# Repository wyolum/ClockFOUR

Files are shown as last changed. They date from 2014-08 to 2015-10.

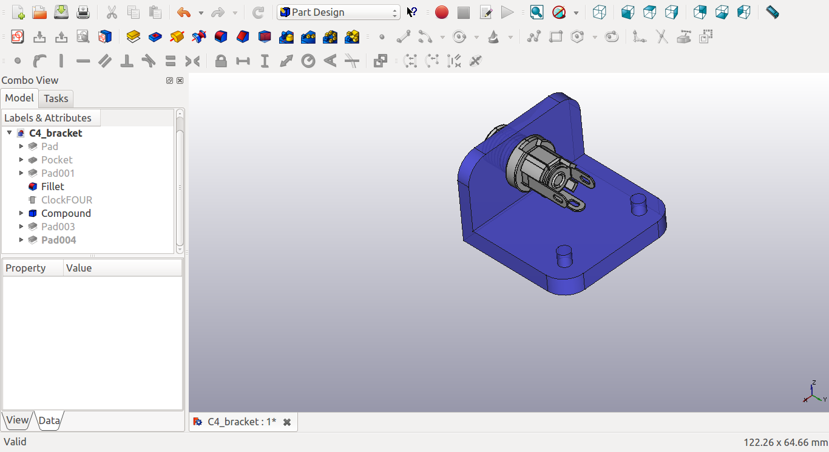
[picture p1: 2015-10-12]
fabricate/Power_Socket_Bracket/C4_bracket_06.png

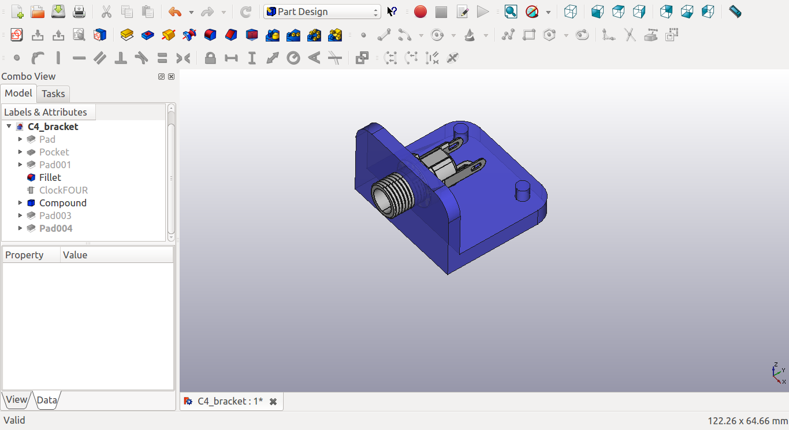
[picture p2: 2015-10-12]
fabricate/Power_Socket_Bracket/C4_bracket_05.png

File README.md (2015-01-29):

ClockFOUR
=========

ClockFOUR is a word clock that tells time with words.  It has a 14x13 matrix of letters that, when illuminated, tells time to the minute.  e.g. “SEVENTEEN MINUTES PAST FOUR”  The clock is 28 x 28 x ~2.6 cm.  The main PCB is approximately 24 x 22 cm and has 182 RGB WS2812B pixels on the front.  The back of the PCB contains an Arduino compatible 328P microprocessor and a DS3231 real time clock chip with 2032 battery backup.  Power is provided by a quality international multi-voltage 5V 3A power supply with barrel connector.

The user interface consists of two touch sensitive buttons wired to top two metal screw posts. Modes and settings are actuated by short taps and long presses.

Development team:
David Pincus (Project leader, software, hardware & design)
Josef Schneider (Software)
Anool Mahidharia (Hardware)

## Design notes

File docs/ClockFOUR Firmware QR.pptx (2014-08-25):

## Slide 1

ClockTiM Firmware 1.0 Quick Reference

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
<Power on>

L

R

Wyolum logo displayed for 3 seconds

Seconds mode

Temperature mode

Splash mode

L

Self test mode

Time mode

Colour ++

L

/

R

L

L

R

L

Set time mode

L

&

R

Enter choice

GPS? Y/N

If N

L

R

If Y – Time and date set by GPS

R – display next hour using words, e.g. ONE, TWO, THREE, FOUR… L – select

Display two large matrix digits with the first digit highlighted. R- advances by 10 minutes per press, e.g. 10, 20, 30. L – select. R – advance minute digit by 1, e.g. 30, 31, 32, 33, etc. L – select.

Toggle Y / N

Set hour mode

Set minute mode (10’s then 1’s)

Set degree mode C/F

L

Deg C/F?

Toggle C/F

R

Last updated 30/7/14

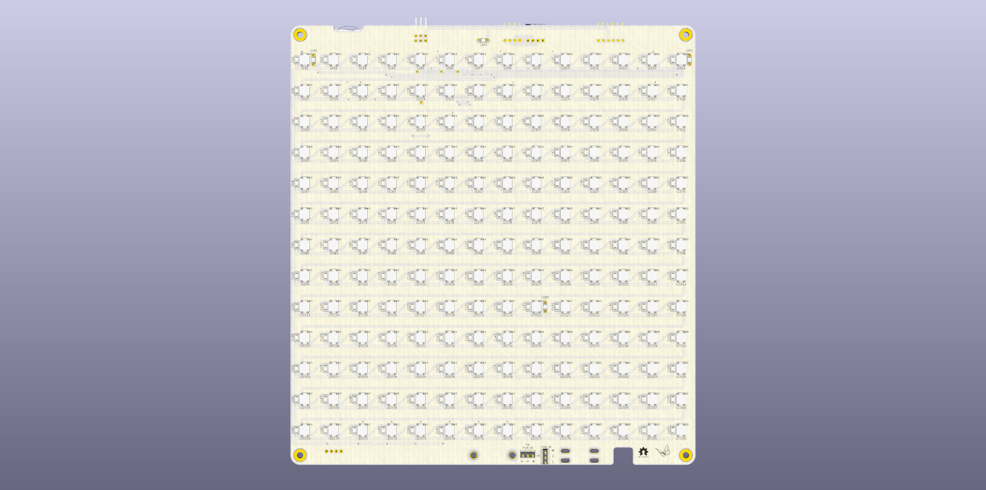
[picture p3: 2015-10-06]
KiCad_bak/3D_Render/ClockFOUR2.png

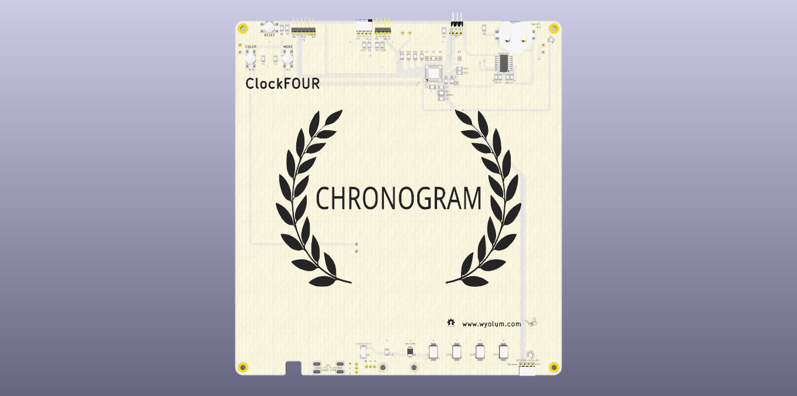
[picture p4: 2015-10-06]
KiCad_bak/3D_Render/ClockFOUR1.png

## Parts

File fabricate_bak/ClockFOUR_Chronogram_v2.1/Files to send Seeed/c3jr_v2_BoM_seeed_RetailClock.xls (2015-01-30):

Electronic Engineering BOM List
Product Name： ClockFOUR – Retail , complete assembled unit
Version：V0.1 | 2.0
Issue Date：29/1/2015
Item No. (序号) | Reference Des (上件位置) | Qty (用量) | Catalog (分类） | Part_Description (规格描述) | Part_Value （元件值） | Part_Package （元件封装） | Manufacturers Name (使用厂牌名称) | Manufacturers Part No. (使用厂牌型号) | Distributors Name （供应商名称） | Distributors Part No. (供貨商型号) | Unit Price （单价） | Price Break To Use （价格分段的购买量） | Notes/Remark （备注）
Example（填写范例）
1 | c4_v2_BoM_seeed | 1 | OTHER | ClockFOUR from Seeed BOM |  | c4_v2_BoM_seeed | Seeed Studio Parts kit and PCB from supplied BOM
2 | baffles_v2_C4.pdf | 15 | OTHER | Vertical Baffle (216x14x2mm black acrylic; 15 per clock) |  | 2mm Thick Acrylic, Black | Laser Cut
3 | baffles_v2_C4.pdf | 14 | OTHER | Horizontal Baffle (218x16x2mm black acrylic; 14 per clock) |  | 2mm Thick Acrylic, Black | Laser Cut
4 | baffles_v2_C4.pdf | 12 | OTHER | Round Localizing Washers (2mm Acrylic Black; Rout=4mm, Rin=1.5mm; 12 per clock) |  | 2mm Thick Acrylic, Black | Laser Cut
5 | sides_C4_v2.pdf | 1 | OTHER | Top, bottom, left & right sides (276 & 270 x20x3mm SMOKED Acrylic) |  | 3mm Thick, Acrylic, SMOKED | Laser Cut
6 | backplate_C4_v2.pdf | 1 | OTHER | Back Plate (280x280x3mm SMOKED Acrylic; Laser cut and etched) |  | 3mm Thick, Acrylic, SMOKED | Laser Cut + Engrave
7 | frontplate_C4_v2.pdf | 1 | OTHER | Front Plate (3mm CLEAR Acrylic; Painted flat black (3 coats), Laser cut and etched) |  | 3mm Thick, Acrylic, Clear | Laser Cut + Engrave
8 |  |  | OTHER | Spray paint front plate (2-3x coats flat black) |  | Flat black spray paint - 2-3x coats, let dry between coats | Seeed Studio
9 |  | 4 | OTHER | M3 Stand Offs 20mm, - Part No : 94868A229 |  | Standoff, M3x20mm, Round, SS | McMaster | 94868A229 |  |  |  |  | http://www.mcmaster.com/#catalog/120/3264/=vcmf9b
10 |  | 4 | OTHER | M3 16mm low head hex screws - Part No : 92855A316 |  | Screw, M3x16mm, Low Head Socket, SS | McMaster | 92855A316 |  |  |  |  | http://www.mcmaster.com/#metric-socket-head-cap-screws/=jroaog
11 |  | 8 | OTHER | M3 10mm low head hex screws - Part No : 92855A310 |  | Screw, M3x10mm, Low Head Socket, SS | McMaster | 92855A310 |  |  |  |  | http://www.mcmaster.com/#catalog/121/3100/=vfpcjh
12 |  | 4 | OTHER | M3 hex nut - Part No : 91828A211 |  | Nut, M3, Hex, SS | McMaster | 91828A211 |  |  |  |  | http://www.mcmaster.com/#metric-hex-nuts/=jroctc
13 |  | 1 | OTHER | Power Supply (5v 3A plug in; plugs for USA, UK, Europe and Australia/China included) |  | ADPT MULTI-BLADE 5VDC 3.0A P5P | CUI inc | EMSA050300-P5P-SZ | Digikey | T1088-P5P-ND |  |  | http://www.digikey.com/product-detail/en/EMSA050300-P5P-SZ/T1088-P5P-ND/2352082
14 | C4 Instructions_v1.pdf | 1 | OTHER | Instructions sheet (1 printed page B&W A4 size) |  |  | Seeed Studio
15 |  | 1 | OTHER | Velum Paper (220x220mm)
16 |  | 4 | OTHER | clear tape (to hold down velum paper)
17 |  | 1 | OTHER | CR2032 3v lithium coin cell |  |  |  |  | Digikey | P189-ND |  |  | http://www.digikey.com/product-detail/en/CR2032/P189-ND/31939
17 |  | 1 | Connector | CONN 2.1MM JACK W/HARD PNL MNT |  |  | CUI Inc | PJ-005A | Digikey | CP-5-ND |  |  | http://www.digikey.com/product-detail/en/PJ-005A/CP-5-ND/165838
18 |  | 1 | Connector | 5-10cm Wires to connect power jack to PCB - solder both sides |  |  | Seeed Studio
19 |  | 1 | OTHER | Packaging material - securely prepare clock for international trasport
20 |  | 4 | OTHER | BUMPER CYLINDRICAL, Tapered0.5" DIA BLK |  |  | 3M | SJ-5012 (BLACK) | Digikey | SJ5012-0-ND |  |  | PARTS KIT ONLY - Customer to install on bottom or back of clock
1. Recommended Distributor: Digi-Key, Mouser, Avnet Express, Farnell.
2. Catalog: Capacitor,Resister,Diode,Connector,Transistor,IC,PROTECTOR CATEGORY,OTHER
3. Required Fields: Item No, Reference Des, Qty, Catalog, Part_Value, Part Package
Optional Fields: Part_Description, Manufacturers Name, Manufacturers Part No, Distributors Name, Distributors Part No, Unit Cost, Price break to use, Notes/Remark

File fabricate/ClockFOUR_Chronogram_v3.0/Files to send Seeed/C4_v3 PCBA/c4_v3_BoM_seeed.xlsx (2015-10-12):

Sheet: Seeed BOM Format
Electronic Engineering BOM List
Product Name： Chronogram
Version：V3.0
Issue Date：07/OCT/2015
Item No. (序号) | Reference Des (上件位置) | Qty (用量) | Catalog (分类） | Part_Description (规格描述) | Part_Value （元件值） | Part_Package （元件封装） | Manufacturers Name (使用厂牌名称) | Manufacturers Part No. (使用厂牌型号) | Distributors Name （供应商名称） | Distributors Part No. (供貨商型号) | Unit Price （单价） | Price Break To Use （价格分段的购买量） | Notes/Remark （备注）
Example（填写范例）
1 | BT1 | 1 | OTHER | HOLDER COIN CELL 20MM SMD | Batt_RTC | 2032 | MPD (Memory Protection Devices) | BK-912 | Digikey | BK-912-ND |  |  | http://www.digikey.com/product-detail/en/BK-912/BK-912-ND/2647825
2 | -- | 1 | OTHER | BATTERY LITHIUM 3V COIN 20MM | CR2032 | 2032 | Panasonic – BSG | CR2032 | Digikey | P189-ND |  |  | http://www.digikey.com/product-detail/en/CR2032/P189-ND/31939
3 | C1,C3,C6,C8,C9,C11, C197,C198,C199 | 9 | Capacitor | CAP CER 0.1UF 25V 10% X7R 0805 | 100nF | 0805 (2012 Metric) | Samsung Electro-Mechanics America, Inc | CL21B104KACNNNC | Digikey | 1276-1099-1-ND |  |  | http://www.digikey.com/product-detail/en/CL21B104KACNNNC/1276-1099-1-ND/3889185
4 | C5,C7 | 2 | Capacitor | CAP CER 22PF 100V 5% NP0 0805 | 22pF | 0805 (2012 Metric) | Samsung Electro-Mechanics America, Inc | CL21C220JCANNNC | Digikey | 1276-2607-1-ND |  |  | http://www.digikey.com/product-detail/en/CL21C220JCANNNC/1276-2607-1-ND/3890693
5 | C10,C194,C195,C196 | 4 | Capacitor | CAP ALUM 47UF 16V 20% SMD | 47uF | 2917 (7343 Metric) | Panasonic Electronic Components | EEF-CX1C470R | Digikey | P16815-1-ND |  |  | http://www.digikey.com/product-detail/en/EEF-CX1C470R/P16815-1-ND/4755585
6 | C12 ~ C193 | 182 | Capacitor | CAP CER 0.1UF 25V 10% X7R 0805 | 100nF | 0805 (2012 Metric) | Samsung Electro-Mechanics America, Inc | CL21B104KACNNNC | Digikey | 1276-1099-1-ND |  |  | http://www.digikey.com/product-detail/en/CL21B104KACNNNC/1276-1099-1-ND/3889185
7 | D1 | 1 | Diode | DIODE ZENER 5.6V 5W DO214AA | SMBJ5339B | DO-214AA, SMB | Micro Commercial Co | SMBJ5339B-TP | Digikey | SMBJ5339B-TPMSCT-ND |  |  | http://www.digikey.com/product-detail/en/SMBJ5339B-TP/SMBJ5339B-TPMSCT-ND/1636205
8 | F1 | 1 | PROTECTOR CATEGORY | Resettable Fuse, POLYSWITCH 16V 2.0A SMD | MiniSMDC200F/16 | 1812 (4532 Metric) | TE Connectivity / Raychem | MINISMDC200F/16-2 | Mouser | 650-MINISMDC200F/162 |  |  | http://www.mouser.ee/ProductDetail/TE-Connectivity-Raychem/MINISMDC200F-16-2/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
9 | LDR4 | 1 | Resister | PHOTOCELL 16-33KOHM | 15k | Thru' Hole | Advanced Photonix Inc | PDV-P8103 | Digikey | PDV-P8103-ND |  |  | http://www.digikey.com/product-detail/en/PDV-P8103/PDV-P8103-ND/480610
10 | LED1 ~ LED182 | 182 | OTHER | WS2812B;4pin;5050 SMD RGB LED with built-in WS2811 IC | WS2812B | 5050 | Ray wu's store Store No.701799 | WS2812B | Ali Express | WS2812B |  |  | http://www.aliexpress.com/store/product/100pcs-WS2812B-4pin-5050-SMD-RGB-LED-with-built-in-WS2811-IC-inside/701799_1202415085.html
11 | P1 | 1 | Connector | CONN HEADER 6POS .100 R/A 15AU DUAL STR | ICSP | Dual row, 0.1” | FCI | 68021-206HLF | Digikey | 609-3343-ND |  |  | http://www.digikey.com/product-detail/en/68021-206HLF/609-3343-ND/1878487
12 | P2, P3 | 1 | Connector | CONN HEADER .100" SNGL STR | FTDI, HEADER_3x1_PWR | 0.100" (2.54mm) Pitch Connector Male | Sullins Connector Solutions | PREC040SAAN-RC | Digikey | S1012EC-40-ND |  |  | http://www.digikey.com/product-detail/en/PREC040SAAN-RC/S1012EC-40-ND/2774814
13 | P5 | 1 | Connector | CONN HEADER .100" SNGL R/A 3POS | HEADER_3x1_PWR | 0.100" (2.54mm) Pitch Connector Male | Sullins Connector Solutions | PRPC003SBAN-M71RC | Digikey | S1111EC-03-ND |  |  | http://www.digikey.com/product-detail/en/PRPC003SBAN-M71RC/S1111EC-03-ND/2775331
14 | R1,R4 | 2 | Resister | RES 470 OHM 1/8W 5% 0805 | 470R | 0805 (2012 Metric) | Stackpole Electronics Inc | RMCF0805JT470R | Digikey | RMCF0805JT470RCT-ND |  |  | http://www.digikey.com/product-detail/en/RMCF0805JT470R/RMCF0805JT470RCT-ND/1942551
15 | R2,R3,R5,R6,R7,R10, R11,R14,R15,R16 | 10 | Resister | RES 10K OHM 1/8W 1% 0805 | 10K | 0805 (2012 Metric) | Stackpole Electronics Inc | RMCF0805FT10K0 | Digikey | RMCF0805FT10K0CT-ND |  |  | http://www.digikey.com/product-detail/en/RMCF0805FT10K0/RMCF0805FT10K0CT-ND/1942435
16 | R8,R9 | 2 | Resister | RES 4.7K OHM 1/8W 5% 0805 | 4K7 | 0805 (2012 Metric) | Stackpole Electronics Inc | RMCF0805JT4K70 | Digikey | RMCF0805JT4K70CT-ND |  |  | http://www.digikey.com/product-detail/en/RMCF0805JT4K70/RMCF0805JT4K70CT-ND/1942570
17 | SW1, SW2, SW3 | 3 | OTHER | SWITCH TACTILE SPST-NO 0.05A 24V | SW_RST, SW_L, SW_R | 6.00mm x 6.00mm SMD | TE Connectivity | FSM6JSMA | Digikey | 450-1133-ND |  |  | http://www.digikey.com/product-detail/en/FSM6JSMA/450-1133-ND/525822
18 | U1 | 1 | IC | IC MCU 8BIT 32KB FLASH 32TQFP | ATMEGA328P | 32-TQFP | Atmel | ATMEGA328P-AU | Digikey | ATMEGA328P-AU-ND |  |  | http://www.digikey.com/product-detail/en/ATMEGA328P-AU/ATMEGA328P-AU-ND/1832260
19 | U2 | 1 | IC | IC RTC CLK/CALENDAR I2C 16-SOIC | DS3231N | 16-SOIC (0.295", 7.50mm Width) | Maxim Integrated Products | DS3231S# | Digikey | DS3231S#-ND |  |  | http://www.digikey.com/product-detail/en/DS3231S%23/DS3231S%23-ND/1197574
20 | X1 | 1 | OTHER | CRYSTAL 16MHZ 9PF SMD | 16MHz | 4-SMD, No Lead (DFN, LCC) | EPSON | TSX-3225 16.0000MF09Z-AC3 | Digikey | SER3628CT-ND |  |  | http://www.digikey.com/product-detail/en/TSX-3225%2016.0000MF09Z-AC3/SER3628CT-ND/1802879
PARTS KIT (DO NOT POPULATE)
1 | P9, P10 | 2 | Connector | CONN HEADER .100" SNGL STR | STACK_R, Marquee | 0.100" (2.54mm) Pitch Connector Male | Sullins Connector Solutions | PREC040SAAN-RC | Digikey | S1012EC-40-ND |  |  | http://www.digikey.com/product-detail/en/PREC040SAAN-RC/S1012EC-40-ND/2774814
2 | P6, P8, R12, R13 | 4 | Resister | RES 0.0 OHM 1/8W JUMP 0805 | 5VEN_L, 5VEN_R, 0R, 0R | 0805 (2012 Metric) | Samsung Electro-Mechanics America, Inc | RC2012J000CS | Digikey | 1276-5466-1-ND |  |  | http://www.digikey.com/product-detail/en/RC2012J000CS/1276-5466-1-ND/3968438
3 | P7 | 1 | Connector | CONN HEADER FEMALE 4POS .1" TIN | STACK_L | 0.100" (2.54mm) Pitch Connector Female | Sullins Connector Solutions | PPTC041LFBN-RC | Digikey | S7002-ND |  |  | http://www.digikey.com/product-detail/en/PPTC041LFBN-RC/S7002-ND/810144
1. Recommended Distributor: Digi-Key, Mouser, Avnet Express, Farnell.
2. Catalog: Capacitor,Resister,Diode,Connector,Transistor,IC,PROTECTOR CATEGORY,OTHER
3. Required Fields: Item No, Reference Des, Qty, Catalog, Part_Value, Part Package
Optional Fields: Part_Description, Manufacturers Name, Manufacturers Part No, Distributors Name, Distributors Part No, Unit Cost, Price break to use, Notes/Remark

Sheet: Sheet4
Id | Designator | Package | Quantity | Designation | Supplier and ref
1 | BT1 | CR2032_SMD2 | 1 | Batt_RTC
2 | C1,C3,C6,C8,C9,C11,C197,C198,C199 | c_0805 | 9 | 100n
3 | C5,C7 | c_0805 | 2 | 22p
4 | C10,C194,C195,C196 | c_2917 | 4 | 47u
5 | C193,C192,C191, C190,C189,C188,C187,C186,C185,C184,C183,C182,C181, C180,C179,C178,C177,C176,C175,C174,C173,C172,C171, C170,C169,C168,C167,C166,C165,C164,C163,C162,C161, C160,C159,C158,C157,C156,C155,C154,C153,C152,C151, C150,C149,C148,C147,C146,C145,C144,C143,C142,C141, C140,C139,C138,C137,C136,C135,C134,C133,C132,C131, C130,C129,C128,C127,C126,C125,C124,C123,C122,C121, C120,C119,C118,C117,C116,C115,C114,C113,C112,C111, C110,C109,C108,C107,C106,C105,C104,C103,C102,C101, C100,C99,C98,C97,C96,C95,C94,C93,C92,C91, C90,C89,C88,C87,C86,C85,C84,C83,C82,C81, C80,C79,C78,C77,C76,C75,C74,C73,C72,C71, C70,C69,C68,C67,C66,C65,C64,C63,C62,C61, C60,C59,C58,C57,C56,C55,C54,C53,C52,C51, C50,C49,C48,C47,C46,C45,C44,C43,C42,C41, C40,C39,C38,C37,C36,C35,C34,C33,C32,C31, C30,C29,C28,C27,C26,C25,C24,C23,C22,C21, C20,C19,C18,C17,C16,C15,C14,C13,C12 | c_0805_led | 182 | 100n
6 | D1 | diode-DO214AA | 1 | SMBJ5339B
7 | F1 | f_1812 | 1 | miniSMDC200F/16
8 | LDR4 | r_0805_ldr | 1 | LDR
9 | LED182,LED181, LED180,LED179,LED178,LED177,LED176,LED175,LED174,LED173,LED172,LED171, LED170,LED169,LED168,LED167,LED166,LED165,LED164,LED163,LED162,LED161, LED160,LED159,LED158,LED157,LED156,LED155,LED154,LED153,LED152,LED151, LED150,LED149,LED148,LED147,LED146,LED145,LED144,LED143,LED142,LED141, LED140,LED139,LED138,LED137,LED136,LED135,LED134,LED133,LED132,LED131, LED130,LED129,LED128,LED127,LED126,LED125,LED124,LED123,LED122,LED121, LED120,LED119,LED118,LED117,LED116,LED115,LED114,LED113,LED112,LED111, LED110,LED109,LED108,LED107,LED106,LED105,LED104,LED103,LED102,LED101, LED100,LED99,LED98,LED97,LED96,LED95,LED94,LED93,LED92,LED91, LED90,LED89,LED88,LED87,LED86,LED85,LED84,LED83,LED82,LED81, LED80,LED79,LED78,LED77,LED76,LED75,LED74,LED73,LED72,LED71, LED70,LED69,LED68,LED67,LED66,LED65,LED64,LED63,LED62,LED61, LED60,LED59,LED58,LED57,LED56,LED55,LED54,LED53,LED52,LED51, LED50,LED49,LED48,LED47,LED46,LED45,LED44,LED43,LED42,LED41, LED40,LED39,LED38,LED37,LED36,LED35,LED34,LED33,LED32,LED31, LED30,LED29,LED28,LED27,LED26,LED25,LED24,LED23,LED22,LED21, LED20,LED19,LED18,LED17,LED16,LED15,LED14,LED13,LED12,LED11, LED10,LED9,LED8,LED7,LED6,LED5,LED4,LED3,LED2,LED1 | RGB_WS2811B | 182 | WS2812B
10 | P1 | ISP | 1 | ICSP
11 | P2 | Header_FTDI | 1 | FTDI
12 | P3,P5 | Header_3x1_PWR | 2 | PWR_IN
13 | R1,R4 | r_0805 | 2 | 470R
14 | R2,R3,R5,R6,R7,R10,R11,R14,R15,R16 | r_0805 | 10 | 10K
15 | R8,R9 | r_0805 | 2 | 4K7
16 | SW1 | SW_SMD | 1 | SW_RST
17 | SW2 | SW_SMD | 1 | SW_L
18 | SW3 | SW_SMD | 1 | SW_R
19 | U1 | TQFP32 | 1 | ATMEGA328P
20 | U2 | DS3231 | 1 | DS3231N
21 | X1 | Xtal_SMD3 | 1 | 16MHz
 | DNP
1 | P6 | r_0805 | 1 | 5VEN_L
2 | P7 | STACK-L | 1 | I2C_L
3 | P8 | r_0805 | 1 | 5VEN_R
4 | P9 | STACK-R | 1 | I2C_R
5 | P10 | Header_4x1 | 1 | Marquee
6 | R12,R13 | r_0805 | 2 | 0R
7 | LDR1,LDR2,LDR3 | r_0805_ldr | 3 | LDR

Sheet: BoM_PCB
Id | Designator | Package | Quantity | Designation | Supplier and ref
1 | BT1 | CR2032_SMD2 | 1 | Batt_RTC
2 | C1,C3,C6,C8,C9,C11,C197,C198,C199 | c_0805 | 9 | 100n
3 | C5,C7 | c_0805 | 2 | 22p
4 | C10,C194,C195,C196 | c_2917 | 4 | 47u
5 | C193,C192,C191,C190,C189,C188,C187,C186,C185,C184,C183,C182,C181,C180,C179,C178,C177,C176,C175,C174,C173,C172,C171,C170,C169,C168,C167,C166,C165,C164,C163,C162,C161,C160,C159,C158,C157,C156,C155,C154,C153,C152,C151,C150,C149,C148,C147,C146,C145,C144,C143,C142,C141,C140,C139,C138,C137,C136,C135,C134,C133,C132,C131,C130,C129,C128,C127,C126,C125,C124,C123,C122,C121,C120,C119,C118,C117,C116,C115,C114,C113,C112,C111,C110,C109,C108,C107,C106,C105,C104,C103,C102,C101,C100,C99,C98,C97,C96,C95,C94,C93,C92,C91,C90,C89,C88,C87,C86,C85,C84,C83,C82,C81,C80,C79,C78,C77,C76,C75,C74,C73,C72,C71,C70,C69,C68,C67,C66,C65,C64,C63,C62,C61,C60,C59,C58,C57,C56,C55,C54,C53,C52,C51,C50,C49,C48,C47,C46,C45,C44,C43,C42,C41,C40,C39,C38,C37,C36,C35,C34,C33,C32,C31,C30,C29,C28,C27,C26,C25,C24,C23,C22,C21,C20,C19,C18,C17,C16,C15,C14,C13,C12 | c_0805_led | 182 | 100n
6 | D1 | diode-DO214AA | 1 | SMBJ5339B
7 | F1 | f_1812 | 1 | miniSMDC200F/16
8 | LDR4 | r_0805_ldr | 1 | LDR
9 | LED20,LED182,LED181,LED180,LED179,LED178,LED177,LED176,LED175,LED174,LED173,LED172,LED171,LED170,LED169,LED168,LED167,LED166,LED165,LED164,LED163,LED162,LED161,LED160,LED159,LED158,LED157,LED156,LED155,LED154,LED153,LED152,LED151,LED150,LED149,LED148,LED147,LED146,LED145,LED144,LED143,LED142,LED141,LED140,LED139,LED138,LED137,LED136,LED135,LED134,LED133,LED132,LED131,LED130,LED129,LED128,LED127,LED126,LED125,LED124,LED123,LED122,LED121,LED120,LED119,LED118,LED117,LED116,LED115,LED114,LED113,LED112,LED111,LED110,LED109,LED108,LED107,LED106,LED105,LED104,LED103,LED102,LED101,LED100,LED99,LED98,LED97,LED96,LED95,LED94,LED93,LED92,LED91,LED90,LED89,LED88,LED87,LED86,LED85,LED84,LED83,LED82,LED81,LED80,LED79,LED78,LED77,LED76,LED75,LED74,LED73,LED72,LED71,LED70,LED69,LED68,LED67,LED66,LED65,LED64,LED63,LED62,LED61,LED60,LED59,LED58,LED57,LED56,LED55,LED54,LED53,LED52,LED51,LED50,LED49,LED48,LED47,LED46,LED45,LED44,LED43,LED42,LED41,LED40,LED39,LED38,LED37,LED36,LED35,LED34,LED33,LED32,LED31,LED30,LED29,LED28,LED27,LED26,LED25,LED24,LED23,LED22,LED21,LED19,LED18,LED17,LED16,LED15,LED14,LED13,LED12,LED11,LED10,LED9,LED8,LED7,LED6,LED5,LED4,LED3,LED2,LED1 | RGB_WS2811B | 182 | WS2812B
10 | P1 | ISP | 1 | ICSP
11 | P2 | Header_FTDI | 1 | FTDI
12 | P3,P5 | Header_3x1_PWR | 2 | PWR_IN
13 | R1,R4 | r_0805 | 2 | 470R
14 | R2,R3,R5,R6,R7,R10,R11,R14,R15,R16 | r_0805 | 10 | 10K
15 | R8,R9 | r_0805 | 2 | 4K7
16 | SW1 | SW_SMD | 1 | SW_RST
17 | SW2 | SW_SMD | 1 | SW_L
18 | SW3 | SW_SMD | 1 | SW_R
19 | U1 | TQFP32 | 1 | ATMEGA328P
20 | U2 | DS3231 | 1 | DS3231N
21 | X1 | Xtal_SMD3 | 1 | 16MHz
 | DNP
22 | P6 | r_0805 | 1 | 5VEN_L
23 | P7 | STACK-L | 1 | I2C_L
24 | P8 | r_0805 | 1 | 5VEN_R
25 | P9 | STACK-R | 1 | I2C_R
26 | P10 | Header_4x1 | 1 | Marquee
27 | R12,R13 | r_0805 | 2 | 0R
28 | LDR1,LDR2,LDR3 | r_0805_ldr | 3 | LDR
 | OTHERS
29 | A6,A7,B2,D7 | BreakOutPad | 4 | CONN_1
30 | L1 | Logo_silk_OSHW_6x6mm | 1 | OSHW
31 | L2,L3 | Logo-WL3 | 2 | Wyolum
32 | L4 | Logo_silk_OSHW_6x6mm | 1 | Chronogram
33 | L5 | wreath2 | 1 | LOGO
34 | S1,S2,S3,S4 | Screw_3mm | 4 | CONN_1
35 | S5,S6 | MtgHole_3mm | 2 | CONN_1
36 | S13,S12,S11,S10 | Slot_tiewrap | 4 | CONN_1

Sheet: BoM_SCH
Reference | Value | Footprint
A6 | CONN_1 | C4_Pretty:BreakOutPad
A7 | CONN_1 | C4_Pretty:BreakOutPad
B2 | CONN_1 | C4_Pretty:BreakOutPad
BT1 | Batt_RTC | C4_Pretty:CR2032_SMD2
C1 | 100n | C4_Pretty:c_0805
C3 | 100n | C4_Pretty:c_0805
C5 | 22p | C4_Pretty:c_0805
C6 | 100n | C4_Pretty:c_0805
C7 | 22p | C4_Pretty:c_0805
C8 | 100n | C4_Pretty:c_0805
C9 | 100n | C4_Pretty:c_0805
C10 | 47u | C4_Pretty:c_2917
C11 | 100n | C4_Pretty:c_0805
C12 | 100n | C4_Pretty:c_0805_led
C13 | 100n | C4_Pretty:c_0805_led
C14 | 100n | C4_Pretty:c_0805_led
C15 | 100n | C4_Pretty:c_0805_led
C16 | 100n | C4_Pretty:c_0805_led
C17 | 100n | C4_Pretty:c_0805_led
C18 | 100n | C4_Pretty:c_0805_led
C19 | 100n | C4_Pretty:c_0805_led
C20 | 100n | C4_Pretty:c_0805_led
C21 | 100n | C4_Pretty:c_0805_led
C22 | 100n | C4_Pretty:c_0805_led
C23 | 100n | C4_Pretty:c_0805_led
C24 | 100n | C4_Pretty:c_0805_led
C25 | 100n | C4_Pretty:c_0805_led
C26 | 100n | C4_Pretty:c_0805_led
C27 | 100n | C4_Pretty:c_0805_led
C28 | 100n | C4_Pretty:c_0805_led
C29 | 100n | C4_Pretty:c_0805_led
C30 | 100n | C4_Pretty:c_0805_led
C31 | 100n | C4_Pretty:c_0805_led
C32 | 100n | C4_Pretty:c_0805_led
C33 | 100n | C4_Pretty:c_0805_led
C34 | 100n | C4_Pretty:c_0805_led
C35 | 100n | C4_Pretty:c_0805_led
C36 | 100n | C4_Pretty:c_0805_led
C37 | 100n | C4_Pretty:c_0805_led
C38 | 100n | C4_Pretty:c_0805_led
C39 | 100n | C4_Pretty:c_0805_led
C40 | 100n | C4_Pretty:c_0805_led
C41 | 100n | C4_Pretty:c_0805_led
C42 | 100n | C4_Pretty:c_0805_led
C43 | 100n | C4_Pretty:c_0805_led
C44 | 100n | C4_Pretty:c_0805_led
C45 | 100n | C4_Pretty:c_0805_led
C46 | 100n | C4_Pretty:c_0805_led
C47 | 100n | C4_Pretty:c_0805_led
C48 | 100n | C4_Pretty:c_0805_led
C49 | 100n | C4_Pretty:c_0805_led
C50 | 100n | C4_Pretty:c_0805_led
C51 | 100n | C4_Pretty:c_0805_led
C52 | 100n | C4_Pretty:c_0805_led
C53 | 100n | C4_Pretty:c_0805_led
C54 | 100n | C4_Pretty:c_0805_led
C55 | 100n | C4_Pretty:c_0805_led
C56 | 100n | C4_Pretty:c_0805_led
C57 | 100n | C4_Pretty:c_0805_led
C58 | 100n | C4_Pretty:c_0805_led
C59 | 100n | C4_Pretty:c_0805_led
C60 | 100n | C4_Pretty:c_0805_led
C61 | 100n | C4_Pretty:c_0805_led
C62 | 100n | C4_Pretty:c_0805_led
C63 | 100n | C4_Pretty:c_0805_led
C64 | 100n | C4_Pretty:c_0805_led
C65 | 100n | C4_Pretty:c_0805_led
C66 | 100n | C4_Pretty:c_0805_led
C67 | 100n | C4_Pretty:c_0805_led
C68 | 100n | C4_Pretty:c_0805_led
C69 | 100n | C4_Pretty:c_0805_led
C70 | 100n | C4_Pretty:c_0805_led
C71 | 100n | C4_Pretty:c_0805_led
C72 | 100n | C4_Pretty:c_0805_led
C73 | 100n | C4_Pretty:c_0805_led
C74 | 100n | C4_Pretty:c_0805_led
C75 | 100n | C4_Pretty:c_0805_led
C76 | 100n | C4_Pretty:c_0805_led
C77 | 100n | C4_Pretty:c_0805_led
C78 | 100n | C4_Pretty:c_0805_led
C79 | 100n | C4_Pretty:c_0805_led
C80 | 100n | C4_Pretty:c_0805_led
C81 | 100n | C4_Pretty:c_0805_led
C82 | 100n | C4_Pretty:c_0805_led
C83 | 100n | C4_Pretty:c_0805_led
C84 | 100n | C4_Pretty:c_0805_led
C85 | 100n | C4_Pretty:c_0805_led
C86 | 100n | C4_Pretty:c_0805_led
C87 | 100n | C4_Pretty:c_0805_led
C88 | 100n | C4_Pretty:c_0805_led
C89 | 100n | C4_Pretty:c_0805_led
C90 | 100n | C4_Pretty:c_0805_led
C91 | 100n | C4_Pretty:c_0805_led
C92 | 100n | C4_Pretty:c_0805_led
C93 | 100n | C4_Pretty:c_0805_led
C94 | 100n | C4_Pretty:c_0805_led
C95 | 100n | C4_Pretty:c_0805_led
C96 | 100n | C4_Pretty:c_0805_led
C97 | 100n | C4_Pretty:c_0805_led
C98 | 100n | C4_Pretty:c_0805_led
C99 | 100n | C4_Pretty:c_0805_led
C100 | 100n | C4_Pretty:c_0805_led
C101 | 100n | C4_Pretty:c_0805_led
C102 | 100n | C4_Pretty:c_0805_led
C103 | 100n | C4_Pretty:c_0805_led
C104 | 100n | C4_Pretty:c_0805_led
C105 | 100n | C4_Pretty:c_0805_led
C106 | 100n | C4_Pretty:c_0805_led
C107 | 100n | C4_Pretty:c_0805_led
C108 | 100n | C4_Pretty:c_0805_led
C109 | 100n | C4_Pretty:c_0805_led
C110 | 100n | C4_Pretty:c_0805_led
C111 | 100n | C4_Pretty:c_0805_led
C112 | 100n | C4_Pretty:c_0805_led
C113 | 100n | C4_Pretty:c_0805_led
C114 | 100n | C4_Pretty:c_0805_led
C115 | 100n | C4_Pretty:c_0805_led
C116 | 100n | C4_Pretty:c_0805_led
C117 | 100n | C4_Pretty:c_0805_led
C118 | 100n | C4_Pretty:c_0805_led
C119 | 100n | C4_Pretty:c_0805_led
C120 | 100n | C4_Pretty:c_0805_led
C121 | 100n | C4_Pretty:c_0805_led
C122 | 100n | C4_Pretty:c_0805_led
C123 | 100n | C4_Pretty:c_0805_led
C124 | 100n | C4_Pretty:c_0805_led
C125 | 100n | C4_Pretty:c_0805_led
C126 | 100n | C4_Pretty:c_0805_led
C127 | 100n | C4_Pretty:c_0805_led
C128 | 100n | C4_Pretty:c_0805_led
C129 | 100n | C4_Pretty:c_0805_led
C130 | 100n | C4_Pretty:c_0805_led
C131 | 100n | C4_Pretty:c_0805_led
C132 | 100n | C4_Pretty:c_0805_led
C133 | 100n | C4_Pretty:c_0805_led
C134 | 100n | C4_Pretty:c_0805_led
C135 | 100n | C4_Pretty:c_0805_led
C136 | 100n | C4_Pretty:c_0805_led
C137 | 100n | C4_Pretty:c_0805_led
C138 | 100n | C4_Pretty:c_0805_led
C139 | 100n | C4_Pretty:c_0805_led
C140 | 100n | C4_Pretty:c_0805_led
C141 | 100n | C4_Pretty:c_0805_led
C142 | 100n | C4_Pretty:c_0805_led
C143 | 100n | C4_Pretty:c_0805_led
C144 | 100n | C4_Pretty:c_0805_led
C145 | 100n | C4_Pretty:c_0805_led
C146 | 100n | C4_Pretty:c_0805_led
C147 | 100n | C4_Pretty:c_0805_led
C148 | 100n | C4_Pretty:c_0805_led
C149 | 100n | C4_Pretty:c_0805_led
C150 | 100n | C4_Pretty:c_0805_led
C151 | 100n | C4_Pretty:c_0805_led
C152 | 100n | C4_Pretty:c_0805_led
C153 | 100n | C4_Pretty:c_0805_led
C154 | 100n | C4_Pretty:c_0805_led
C155 | 100n | C4_Pretty:c_0805_led
C156 | 100n | C4_Pretty:c_0805_led
C157 | 100n | C4_Pretty:c_0805_led
C158 | 100n | C4_Pretty:c_0805_led
C159 | 100n | C4_Pretty:c_0805_led
C160 | 100n | C4_Pretty:c_0805_led
C161 | 100n | C4_Pretty:c_0805_led
C162 | 100n | C4_Pretty:c_0805_led
C163 | 100n | C4_Pretty:c_0805_led
C164 | 100n | C4_Pretty:c_0805_led
C165 | 100n | C4_Pretty:c_0805_led
C166 | 100n | C4_Pretty:c_0805_led
C167 | 100n | C4_Pretty:c_0805_led
C168 | 100n | C4_Pretty:c_0805_led
C169 | 100n | C4_Pretty:c_0805_led
C170 | 100n | C4_Pretty:c_0805_led
C171 | 100n | C4_Pretty:c_0805_led
C172 | 100n | C4_Pretty:c_0805_led
C173 | 100n | C4_Pretty:c_0805_led
C174 | 100n | C4_Pretty:c_0805_led
C175 | 100n | C4_Pretty:c_0805_led
C176 | 100n | C4_Pretty:c_0805_led
C177 | 100n | C4_Pretty:c_0805_led
C178 | 100n | C4_Pretty:c_0805_led
C179 | 100n | C4_Pretty:c_0805_led
C180 | 100n | C4_Pretty:c_0805_led
C181 | 100n | C4_Pretty:c_0805_led
C182 | 100n | C4_Pretty:c_0805_led
C183 | 100n | C4_Pretty:c_0805_led
C184 | 100n | C4_Pretty:c_0805_led
C185 | 100n | C4_Pretty:c_0805_led
C186 | 100n | C4_Pretty:c_0805_led
C187 | 100n | C4_Pretty:c_0805_led
C188 | 100n | C4_Pretty:c_0805_led
C189 | 100n | C4_Pretty:c_0805_led
C190 | 100n | C4_Pretty:c_0805_led
C191 | 100n | C4_Pretty:c_0805_led
C192 | 100n | C4_Pretty:c_0805_led
C193 | 100n | C4_Pretty:c_0805_led
C194 | 47u | C4_Pretty:c_2917
C195 | 47u | C4_Pretty:c_2917
C196 | 47u | C4_Pretty:c_2917
C197 | 100n | C4_Pretty:c_0805
C198 | 100n | C4_Pretty:c_0805
C199 | 100n | C4_Pretty:c_0805
D1 | SMBJ5339B | C4_Pretty:diode-DO214AA
D7 | CONN_1 | C4_Pretty:BreakOutPad
F1 | miniSMDC200F/16 | C4_Pretty:f_1812
L1 | OSHW | C4_Pretty:Logo_silk_OSHW_6x6mm
L2 | Wyolum | C4_Pretty:Logo-WL3
L3 | Wyolum | C4_Pretty:Logo-WL3
L4 | Chronogram | C4_Pretty:Logo_silk_OSHW_6x6mm
L5 | Logo | C4_Pretty:Logo_silk_OSHW_6x6mm
LDR1 | LDR | C4_Pretty:r_0805_ldr
LDR2 | LDR | C4_Pretty:r_0805_ldr
LDR3 | LDR | C4_Pretty:r_0805_ldr
LDR4 | LDR | C4_Pretty:r_0805_ldr
LED1 | WS2812B | C4_Pretty:RGB_WS2811B
LED2 | WS2812B | C4_Pretty:RGB_WS2811B
LED3 | WS2812B | C4_Pretty:RGB_WS2811B
LED4 | WS2812B | C4_Pretty:RGB_WS2811B
LED5 | WS2812B | C4_Pretty:RGB_WS2811B
LED6 | WS2812B | C4_Pretty:RGB_WS2811B
LED7 | WS2812B | C4_Pretty:RGB_WS2811B
LED8 | WS2812B | C4_Pretty:RGB_WS2811B
LED9 | WS2812B | C4_Pretty:RGB_WS2811B
LED10 | WS2812B | C4_Pretty:RGB_WS2811B
LED11 | WS2812B | C4_Pretty:RGB_WS2811B
LED12 | WS2812B | C4_Pretty:RGB_WS2811B
LED13 | WS2812B | C4_Pretty:RGB_WS2811B
LED14 | WS2812B | C4_Pretty:RGB_WS2811B
LED15 | WS2812B | C4_Pretty:RGB_WS2811B
LED16 | WS2812B | C4_Pretty:RGB_WS2811B
LED17 | WS2812B | C4_Pretty:RGB_WS2811B
LED18 | WS2812B | C4_Pretty:RGB_WS2811B
LED19 | WS2812B | C4_Pretty:RGB_WS2811B
LED20 | WS2812B | C4_Pretty:RGB_WS2811B
LED21 | WS2812B | C4_Pretty:RGB_WS2811B
LED22 | WS2812B | C4_Pretty:RGB_WS2811B
LED23 | WS2812B | C4_Pretty:RGB_WS2811B
LED24 | WS2812B | C4_Pretty:RGB_WS2811B
LED25 | WS2812B | C4_Pretty:RGB_WS2811B
LED26 | WS2812B | C4_Pretty:RGB_WS2811B
LED27 | WS2812B | C4_Pretty:RGB_WS2811B
LED28 | WS2812B | C4_Pretty:RGB_WS2811B
LED29 | WS2812B | C4_Pretty:RGB_WS2811B
LED30 | WS2812B | C4_Pretty:RGB_WS2811B
LED31 | WS2812B | C4_Pretty:RGB_WS2811B
LED32 | WS2812B | C4_Pretty:RGB_WS2811B
LED33 | WS2812B | C4_Pretty:RGB_WS2811B
LED34 | WS2812B | C4_Pretty:RGB_WS2811B
LED35 | WS2812B | C4_Pretty:RGB_WS2811B
LED36 | WS2812B | C4_Pretty:RGB_WS2811B
LED37 | WS2812B | C4_Pretty:RGB_WS2811B
LED38 | WS2812B | C4_Pretty:RGB_WS2811B
LED39 | WS2812B | C4_Pretty:RGB_WS2811B
LED40 | WS2812B | C4_Pretty:RGB_WS2811B
LED41 | WS2812B | C4_Pretty:RGB_WS2811B
LED42 | WS2812B | C4_Pretty:RGB_WS2811B
LED43 | WS2812B | C4_Pretty:RGB_WS2811B
LED44 | WS2812B | C4_Pretty:RGB_WS2811B
LED45 | WS2812B | C4_Pretty:RGB_WS2811B
LED46 | WS2812B | C4_Pretty:RGB_WS2811B
LED47 | WS2812B | C4_Pretty:RGB_WS2811B
LED48 | WS2812B | C4_Pretty:RGB_WS2811B
LED49 | WS2812B | C4_Pretty:RGB_WS2811B
LED50 | WS2812B | C4_Pretty:RGB_WS2811B
LED51 | WS2812B | C4_Pretty:RGB_WS2811B
LED52 | WS2812B | C4_Pretty:RGB_WS2811B
LED53 | WS2812B | C4_Pretty:RGB_WS2811B
LED54 | WS2812B | C4_Pretty:RGB_WS2811B
LED55 | WS2812B | C4_Pretty:RGB_WS2811B
LED56 | WS2812B | C4_Pretty:RGB_WS2811B
LED57 | WS2812B | C4_Pretty:RGB_WS2811B
LED58 | WS2812B | C4_Pretty:RGB_WS2811B
LED59 | WS2812B | C4_Pretty:RGB_WS2811B
LED60 | WS2812B | C4_Pretty:RGB_WS2811B
LED61 | WS2812B | C4_Pretty:RGB_WS2811B
LED62 | WS2812B | C4_Pretty:RGB_WS2811B
LED63 | WS2812B | C4_Pretty:RGB_WS2811B
LED64 | WS2812B | C4_Pretty:RGB_WS2811B
LED65 | WS2812B | C4_Pretty:RGB_WS2811B
LED66 | WS2812B | C4_Pretty:RGB_WS2811B
LED67 | WS2812B | C4_Pretty:RGB_WS2811B
LED68 | WS2812B | C4_Pretty:RGB_WS2811B
LED69 | WS2812B | C4_Pretty:RGB_WS2811B
LED70 | WS2812B | C4_Pretty:RGB_WS2811B
LED71 | WS2812B | C4_Pretty:RGB_WS2811B
LED72 | WS2812B | C4_Pretty:RGB_WS2811B
LED73 | WS2812B | C4_Pretty:RGB_WS2811B
LED74 | WS2812B | C4_Pretty:RGB_WS2811B
LED75 | WS2812B | C4_Pretty:RGB_WS2811B
LED76 | WS2812B | C4_Pretty:RGB_WS2811B
LED77 | WS2812B | C4_Pretty:RGB_WS2811B
LED78 | WS2812B | C4_Pretty:RGB_WS2811B
LED79 | WS2812B | C4_Pretty:RGB_WS2811B
LED80 | WS2812B | C4_Pretty:RGB_WS2811B
LED81 | WS2812B | C4_Pretty:RGB_WS2811B
LED82 | WS2812B | C4_Pretty:RGB_WS2811B
LED83 | WS2812B | C4_Pretty:RGB_WS2811B
LED84 | WS2812B | C4_Pretty:RGB_WS2811B
LED85 | WS2812B | C4_Pretty:RGB_WS2811B
LED86 | WS2812B | C4_Pretty:RGB_WS2811B
LED87 | WS2812B | C4_Pretty:RGB_WS2811B
LED88 | WS2812B | C4_Pretty:RGB_WS2811B
LED89 | WS2812B | C4_Pretty:RGB_WS2811B
LED90 | WS2812B | C4_Pretty:RGB_WS2811B
LED91 | WS2812B | C4_Pretty:RGB_WS2811B
LED92 | WS2812B | C4_Pretty:RGB_WS2811B
LED93 | WS2812B | C4_Pretty:RGB_WS2811B
LED94 | WS2812B | C4_Pretty:RGB_WS2811B
LED95 | WS2812B | C4_Pretty:RGB_WS2811B
LED96 | WS2812B | C4_Pretty:RGB_WS2811B
LED97 | WS2812B | C4_Pretty:RGB_WS2811B
LED98 | WS2812B | C4_Pretty:RGB_WS2811B
LED99 | WS2812B | C4_Pretty:RGB_WS2811B
LED100 | WS2812B | C4_Pretty:RGB_WS2811B
LED101 | WS2812B | C4_Pretty:RGB_WS2811B
LED102 | WS2812B | C4_Pretty:RGB_WS2811B
LED103 | WS2812B | C4_Pretty:RGB_WS2811B
LED104 | WS2812B | C4_Pretty:RGB_WS2811B
LED105 | WS2812B | C4_Pretty:RGB_WS2811B
LED106 | WS2812B | C4_Pretty:RGB_WS2811B
LED107 | WS2812B | C4_Pretty:RGB_WS2811B
LED108 | WS2812B | C4_Pretty:RGB_WS2811B
LED109 | WS2812B | C4_Pretty:RGB_WS2811B
LED110 | WS2812B | C4_Pretty:RGB_WS2811B
LED111 | WS2812B | C4_Pretty:RGB_WS2811B
LED112 | WS2812B | C4_Pretty:RGB_WS2811B
LED113 | WS2812B | C4_Pretty:RGB_WS2811B
LED114 | WS2812B | C4_Pretty:RGB_WS2811B
LED115 | WS2812B | C4_Pretty:RGB_WS2811B
LED116 | WS2812B | C4_Pretty:RGB_WS2811B
LED117 | WS2812B | C4_Pretty:RGB_WS2811B
LED118 | WS2812B | C4_Pretty:RGB_WS2811B
LED119 | WS2812B | C4_Pretty:RGB_WS2811B
LED120 | WS2812B | C4_Pretty:RGB_WS2811B
LED121 | WS2812B | C4_Pretty:RGB_WS2811B
LED122 | WS2812B | C4_Pretty:RGB_WS2811B
LED123 | WS2812B | C4_Pretty:RGB_WS2811B
LED124 | WS2812B | C4_Pretty:RGB_WS2811B
LED125 | WS2812B | C4_Pretty:RGB_WS2811B
LED126 | WS2812B | C4_Pretty:RGB_WS2811B
LED127 | WS2812B | C4_Pretty:RGB_WS2811B
LED128 | WS2812B | C4_Pretty:RGB_WS2811B
LED129 | WS2812B | C4_Pretty:RGB_WS2811B
LED130 | WS2812B | C4_Pretty:RGB_WS2811B
LED131 | WS2812B | C4_Pretty:RGB_WS2811B
LED132 | WS2812B | C4_Pretty:RGB_WS2811B
LED133 | WS2812B | C4_Pretty:RGB_WS2811B
LED134 | WS2812B | C4_Pretty:RGB_WS2811B
LED135 | WS2812B | C4_Pretty:RGB_WS2811B
LED136 | WS2812B | C4_Pretty:RGB_WS2811B
LED137 | WS2812B | C4_Pretty:RGB_WS2811B
LED138 | WS2812B | C4_Pretty:RGB_WS2811B
LED139 | WS2812B | C4_Pretty:RGB_WS2811B
LED140 | WS2812B | C4_Pretty:RGB_WS2811B
LED141 | WS2812B | C4_Pretty:RGB_WS2811B
LED142 | WS2812B | C4_Pretty:RGB_WS2811B
LED143 | WS2812B | C4_Pretty:RGB_WS2811B
LED144 | WS2812B | C4_Pretty:RGB_WS2811B
LED145 | WS2812B | C4_Pretty:RGB_WS2811B
LED146 | WS2812B | C4_Pretty:RGB_WS2811B
LED147 | WS2812B | C4_Pretty:RGB_WS2811B
LED148 | WS2812B | C4_Pretty:RGB_WS2811B
LED149 | WS2812B | C4_Pretty:RGB_WS2811B
LED150 | WS2812B | C4_Pretty:RGB_WS2811B
LED151 | WS2812B | C4_Pretty:RGB_WS2811B
LED152 | WS2812B | C4_Pretty:RGB_WS2811B
LED153 | WS2812B | C4_Pretty:RGB_WS2811B
LED154 | WS2812B | C4_Pretty:RGB_WS2811B
LED155 | WS2812B | C4_Pretty:RGB_WS2811B
LED156 | WS2812B | C4_Pretty:RGB_WS2811B
LED157 | WS2812B | C4_Pretty:RGB_WS2811B
LED158 | WS2812B | C4_Pretty:RGB_WS2811B
LED159 | WS2812B | C4_Pretty:RGB_WS2811B
LED160 | WS2812B | C4_Pretty:RGB_WS2811B
LED161 | WS2812B | C4_Pretty:RGB_WS2811B
LED162 | WS2812B | C4_Pretty:RGB_WS2811B
LED163 | WS2812B | C4_Pretty:RGB_WS2811B
LED164 | WS2812B | C4_Pretty:RGB_WS2811B
LED165 | WS2812B | C4_Pretty:RGB_WS2811B
LED166 | WS2812B | C4_Pretty:RGB_WS2811B
LED167 | WS2812B | C4_Pretty:RGB_WS2811B
LED168 | WS2812B | C4_Pretty:RGB_WS2811B
LED169 | WS2812B | C4_Pretty:RGB_WS2811B
LED170 | WS2812B | C4_Pretty:RGB_WS2811B
LED171 | WS2812B | C4_Pretty:RGB_WS2811B
LED172 | WS2812B | C4_Pretty:RGB_WS2811B
LED173 | WS2812B | C4_Pretty:RGB_WS2811B
LED174 | WS2812B | C4_Pretty:RGB_WS2811B
LED175 | WS2812B | C4_Pretty:RGB_WS2811B
LED176 | WS2812B | C4_Pretty:RGB_WS2811B
LED177 | WS2812B | C4_Pretty:RGB_WS2811B
LED178 | WS2812B | C4_Pretty:RGB_WS2811B
LED179 | WS2812B | C4_Pretty:RGB_WS2811B
LED180 | WS2812B | C4_Pretty:RGB_WS2811B
LED181 | WS2812B | C4_Pretty:RGB_WS2811B
LED182 | WS2812B | C4_Pretty:RGB_WS2811B
P1 | ICSP | C4_Pretty:ISP
P2 | FTDI | C4_Pretty:Header_FTDI
P3 | PWR_IN | C4_Pretty:Header_3x1_PWR
P5 | PWR_IN | C4_Pretty:Header_3x1_PWR
P6 | 5VEN_L | C4_Pretty:r_0805
P7 | I2C_L | C4_Pretty:STACK-L
P8 | 5VEN_R | C4_Pretty:r_0805
P9 | I2C_R | C4_Pretty:STACK-R
P10 | Marquee | C4_Pretty:Header_4x1
R1 | 470R | C4_Pretty:r_0805
R2 | 10K | C4_Pretty:r_0805
R3 | 10K | C4_Pretty:r_0805
R4 | 470R | C4_Pretty:r_0805
R5 | 10K | C4_Pretty:r_0805
R6 | 10K | C4_Pretty:r_0805
R7 | 10K | C4_Pretty:r_0805
R8 | 4K7 | C4_Pretty:r_0805
R9 | 4K7 | C4_Pretty:r_0805
R10 | 10K | C4_Pretty:r_0805
R11 | 10K | C4_Pretty:r_0805
R12 | 0R | C4_Pretty:r_0805
R13 | 0R | C4_Pretty:r_0805
R14 | 10K | C4_Pretty:r_0805
R15 | 10K | C4_Pretty:r_0805
R16 | 10K | C4_Pretty:r_0805
S1 | CONN_1 | C4_Pretty:Screw_3mm
S2 | CONN_1 | C4_Pretty:Screw_3mm
S3 | CONN_1 | C4_Pretty:Screw_3mm
S4 | CONN_1 | C4_Pretty:Screw_3mm
S5 | CONN_1 | C4_Pretty:MtgHole_3mm
S6 | CONN_1 | C4_Pretty:MtgHole_3mm
S10 | CONN_1 | C4_Pretty:Slot_tiewrap
S11 | CONN_1 | C4_Pretty:Slot_tiewrap
S12 | CONN_1 | C4_Pretty:Slot_tiewrap
S13 | CONN_1 | C4_Pretty:Slot_tiewrap
SW1 | SW_RST | C4_Pretty:SW_SMD
SW2 | SW_L | C4_Pretty:SW_SMD
SW3 | SW_R | C4_Pretty:SW_SMD
U1 | ATMEGA328P | C4_Pretty:TQFP32
U2 | DS3231N | C4_Pretty:DS3231
X1 | 16MHz | C4_Pretty:Xtal_SMD3

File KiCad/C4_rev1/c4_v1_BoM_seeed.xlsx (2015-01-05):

Electronic Engineering BOM List
Product Name： ClockFOUR
Version：V1.0
Issue Date：10/10/2014
Item No. (序号) | Reference Des (上件位置) | Qty (用量) | Catalog (分类） | Part_Description (规格描述) | Part_Value （元件值） | Part_Package （元件封装） | Manufacturers Name (使用厂牌名称) | Manufacturers Part No. (使用厂牌型号) | Distributors Name （供应商名称） | Distributors Part No. (供貨商型号) | Unit Price （单价） | Price Break To Use （价格分段的购买量） | Notes/Remark （备注）
Example（填写范例）
1 | BT1 | 1 | OTHER | HOLDER COIN CELL 20MM SMD | Batt_RTC | 2032 | MPD (Memory Protection Devices) | BK-912 | Digikey | BK-912-ND |  |  | http://www.digikey.com/product-detail/en/BK-912/BK-912-ND/2647825
2 | C2,C4 | 2 | Capacitor | CAP CER 100PF 50V 10% X7R 0805 | 100pF | 0805 (2012 Metric) | Kemet | C0805C101K5RACTU | Digikey | 399-7981-1-ND |  |  | http://www.digikey.com/product-detail/en/C0805C101K5RACTU/399-7981-1-ND/3471704
3 | C1,C3,C6,C8,C9,C11,C197,C198 | 8 | Capacitor | CAP CER 0.1UF 25V 10% X7R 0805 | 100nF | 0805 (2012 Metric) | Samsung Electro-Mechanics America, Inc | CL21B104KACNNNC | Digikey | 1276-1099-1-ND |  |  | http://www.digikey.com/product-detail/en/CL21B104KACNNNC/1276-1099-1-ND/3889185
4 | C5,C7 | 2 | Capacitor | CAP CER 22PF 100V 5% NP0 0805 | 22pF | 0805 (2012 Metric) | Samsung Electro-Mechanics America, Inc | CL21C220JCANNNC | Digikey | 1276-2607-1-ND |  |  | http://www.digikey.com/product-detail/en/CL21C220JCANNNC/1276-2607-1-ND/3890693
5 | C10,C194,C195,C196 | 4 | Capacitor | CAP ALUM 47UF 16V 20% SMD | 47uF | 2917 (7343 Metric) | Panasonic Electronic Components | EEF-CX1C470R | Digikey | P16815-1-ND |  |  | http://www.digikey.com/product-detail/en/EEF-CX1C470R/P16815-1-ND/4755585
6 | C12 ~ C193 | 182 | Capacitor | CAP CER 0.1UF 25V 10% X7R 0805 | 100nF | 0805 (2012 Metric) | Samsung Electro-Mechanics America, Inc | CL21B104KACNNNC | Digikey | 1276-1099-1-ND |  |  | http://www.digikey.com/product-detail/en/CL21B104KACNNNC/1276-1099-1-ND/3889185
7 | LED1 ~ LED182 | 182 | OTHER | WS2812B;4pin;5050 SMD RGB LED with built-in WS2811 IC | WS2812B | 5050 | Ray wu's store Store No.701799 | WS2812B | Ali Express | WS2812B |  |  | http://www.aliexpress.com/store/product/100pcs-WS2812B-4pin-5050-SMD-RGB-LED-with-built-in-WS2811-IC-inside/701799_1202415085.html
8 | P5 | 1 | Connector | CON PWR JCK 2.0 X 6.0MM W/SHLD | BARREL_JACK | Thru hole, 5.5x2.1 Jack | CUI Inc | PJ-047A | Digikey | CP-047A-ND |  |  | http://www.digikey.com/product-detail/en/PJ-047A/CP-047A-ND/1644575
9 | R1 | 1 | Resister | RES 470 OHM 1/8W 5% 0805 | 470R | 0805 (2012 Metric) | Stackpole Electronics Inc | RMCF0805JT470R | Digikey | RMCF0805JT470RCT-ND |  |  | http://www.digikey.com/product-detail/en/RMCF0805JT470R/RMCF0805JT470RCT-ND/1942551
10 | R3,R4 | 2 | Resister | RES 1M OHM 1/8W 1% 0805 | 1M | 0805 (2012 Metric) | Stackpole Electronics Inc | RMCF0805FT1M00 | Digikey | RMCF0805FT1M00CT-ND |  |  | http://www.digikey.com/product-detail/en/RMCF0805FT1M00/RMCF0805FT1M00CT-ND/1942528
11 | R2,R5,R6,R7 | 4 | Resister | RES 10K OHM 1/8W 1% 0805 | 10K | 0805 (2012 Metric) | Stackpole Electronics Inc | RMCF0805FT10K0 | Digikey | RMCF0805FT10K0CT-ND |  |  | http://www.digikey.com/product-detail/en/RMCF0805FT10K0/RMCF0805FT10K0CT-ND/1942435
12 | R8,R9 | 2 | Resister | RES 4.7K OHM 1/8W 5% 0805 | 4K7 | 0805 (2012 Metric) | Stackpole Electronics Inc | RMCF0805JT4K70 | Digikey | RMCF0805JT4K70CT-ND |  |  | http://www.digikey.com/product-detail/en/RMCF0805JT4K70/RMCF0805JT4K70CT-ND/1942570
13 | SW1 | 1 | OTHER | SWITCH TACTILE SPST-NO 0.05A 12V | SW_RST | 6.00mm x 6.00mm SMD | TE Connectivity | FSM4JSMA | Digikey | 450-1129-ND |  |  | http://www.digikey.com/product-detail/en/FSM4JSMA/450-1129-ND/525821
14 | SW2 | 1 | OTHER | SWITCH TACTILE SPST-NO 0.05A 12V | SW_RST | 6.00mm x 6.00mm SMD | TE Connectivity | FSM4JSMA | Digikey | 450-1129-ND |  |  | http://www.digikey.com/product-detail/en/FSM4JSMA/450-1129-ND/525821
15 | SW3 | 1 | OTHER | SWITCH TACTILE SPST-NO 0.05A 12V | SW_RST | 6.00mm x 6.00mm SMD | TE Connectivity | FSM4JSMA | Digikey | 450-1129-ND |  |  | http://www.digikey.com/product-detail/en/FSM4JSMA/450-1129-ND/525821
16 | U1 | 1 | IC | IC MCU 8BIT 32KB FLASH 32TQFP | ATMEGA328P | 32-TQFP | Atmel | ATMEGA328P-AU | Digikey | ATMEGA328P-AU-ND |  |  | http://www.digikey.com/product-detail/en/ATMEGA328P-AU/ATMEGA328P-AU-ND/1832260
17 | U2 | 1 | IC | IC RTC CLK/CALENDAR I2C 16-SOIC | DS3231N | 16-SOIC (0.295", 7.50mm Width) | Maxim Integrated Products | DS3231S# | Digikey | DS3231S#-ND |  |  | http://www.digikey.com/product-detail/en/DS3231S%23/DS3231S%23-ND/1197574
18 | X1 | 1 | OTHER | CRYSTAL 16MHZ 9PF SMD | 16MHz | 4-SMD, No Lead (DFN, LCC) | EPSON | TSX-3225 16.0000MF09Z-AC3 | Digikey | SER3628CT-ND |  |  | http://www.digikey.com/product-detail/en/TSX-3225%2016.0000MF09Z-AC3/SER3628CT-ND/1802879
PARTS KIT (DO NOT POPULATE)
1 | P1 | 1 | Connector | CONN HEADER .100" DUAL STR 6POS | ICSP | Dual row, 0.1” | Sullins Connector Solutions | PREC003DAAN-RC | Digikey | S2012EC-03-ND |  |  | http://www.digikey.com/product-detail/en/PREC003DAAN-RC/S2012EC-03-ND/2774891
2 | P2, P3, P4, P9 | 4 | Connector | CONN HEADER .100" SNGL STR | FTDI, LDR_Header, Button_Header, I2C_R | 0.100" (2.54mm) Pitch Connector Male | Sullins Connector Solutions | PREC040SAAN-RC | Digikey | S1012EC-40-ND |  |  | http://www.digikey.com/product-detail/en/PREC040SAAN-RC/S1012EC-40-ND/2774814
3 | P6, P8, R12, R13 | 4 | Connector | RES 0.0 OHM 1/8W JUMP 0805 | 5VEN_L, 5VEN_R | 0805 (2012 Metric) | Samsung Electro-Mechanics America, Inc | RC2012J000CS | Digikey | 1276-5466-1-ND |  |  | http://www.digikey.com/product-detail/en/RC2012J000CS/1276-5466-1-ND/3968438
4 | P7 | 1 | Connector | CONN HEADER FEMALE 4POS .1" TIN | I2C_L | 0.100" (2.54mm) Pitch Connector Female | Sullins Connector Solutions | PPTC041LFBN-RC | Digikey | S7002-ND |  |  | http://www.digikey.com/product-detail/en/PPTC041LFBN-RC/S7002-ND/810144
5 | LDR1 | 1 | Resister | PHOTOCELL 16-33KOHM | 16-33KOHM | through hole | Advanced Photonix Inc | PDV-P8103 | Digikey | PDV-P8103-ND |  |  | http://www.digikey.com/product-detail/en/PDV-P8103/PDV-P8103-ND/480610
1. Recommended Distributor: Digi-Key, Mouser, Avnet Express, Farnell.
2. Catalog: Capacitor,Resister,Diode,Connector,Transistor,IC,PROTECTOR CATEGORY,OTHER
3. Required Fields: Item No, Reference Des, Qty, Catalog, Part_Value, Part Package
Optional Fields: Part_Description, Manufacturers Name, Manufacturers Part No, Distributors Name, Distributors Part No, Unit Cost, Price break to use, Notes/Remark

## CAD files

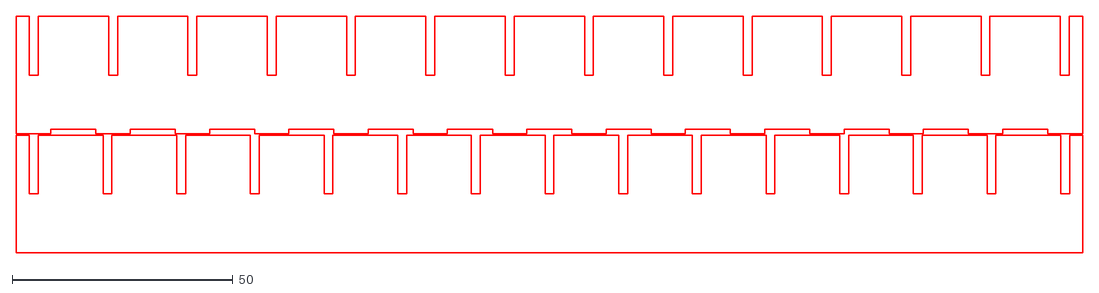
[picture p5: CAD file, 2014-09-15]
fabricate/30x30 size/output/Ready to print/baffles_jr_30_1.0.dxf
241.4 x 53.4

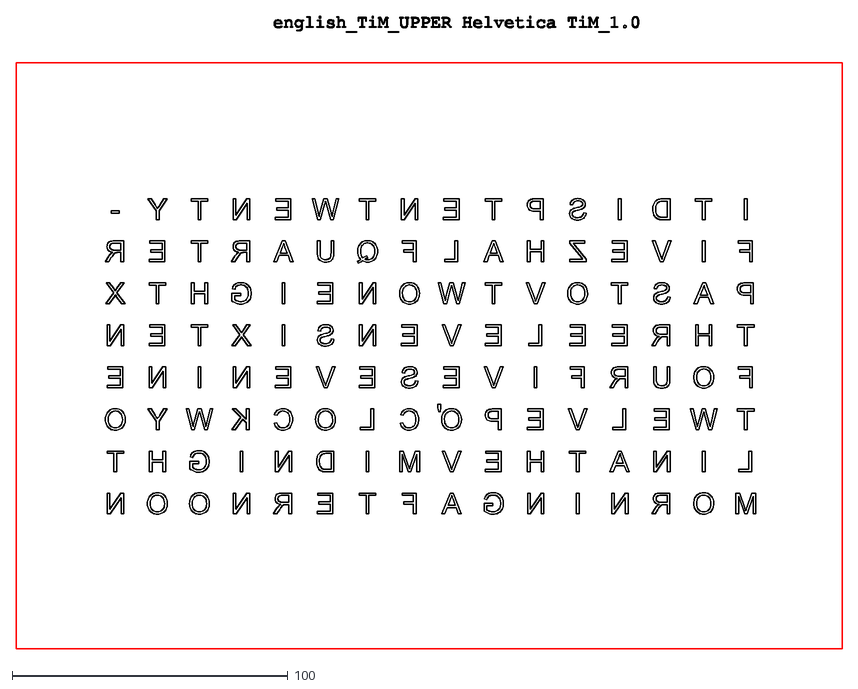
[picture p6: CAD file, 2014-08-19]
fabricate/A4 size/output/english_TiM_UPPER Helvetica_TiM_1.0.dxf
299.5 x 229.3

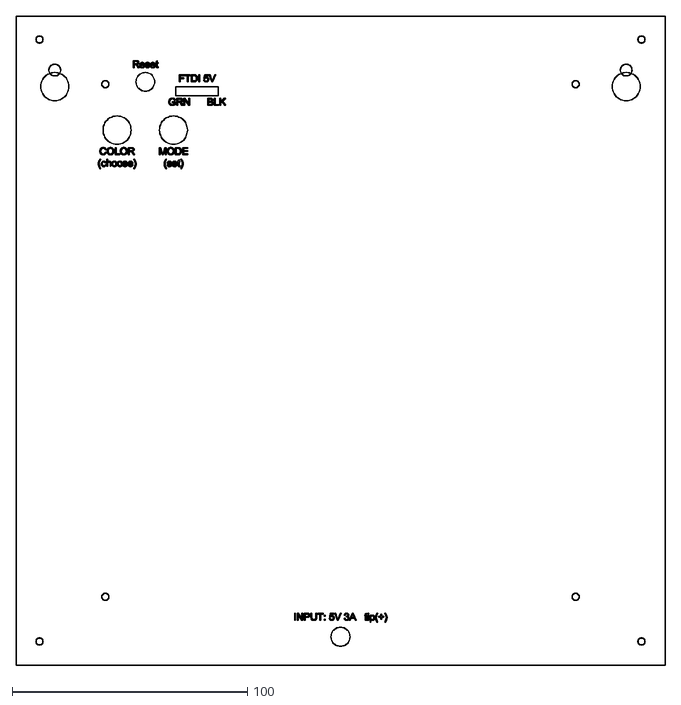
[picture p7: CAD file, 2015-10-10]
fabricate/ClockFOUR_Chronogram_v3.0/output/LASER/backplate_C4_v3.0.dxf
276.0 x 276.0

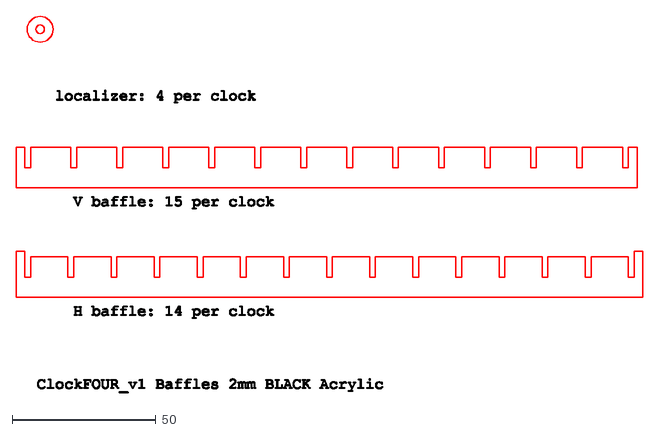
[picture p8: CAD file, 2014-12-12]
fabricate/ClockFOUR_v1/output/1.2mm baffles.dxf
218.0 x 130.9

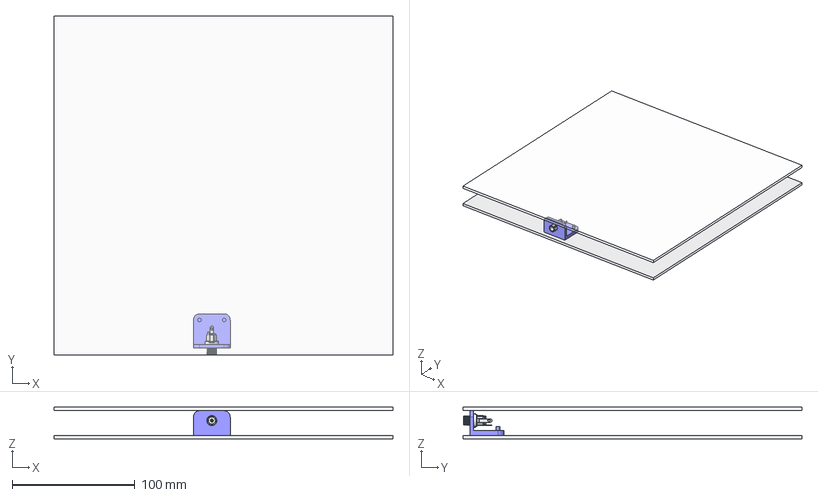
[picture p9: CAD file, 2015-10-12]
fabricate/Power_Socket_Bracket/C4_bracket.fcstd
276.0 x 276.0 x 26.0 mm

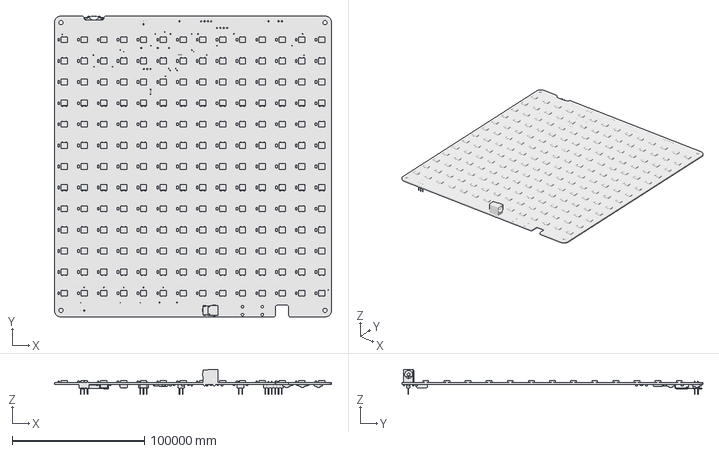
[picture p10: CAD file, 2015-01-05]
KiCad/C4_rev1/ClockFOUR.fcstd
210000.0 x 228020.0 x 19024.1 mm

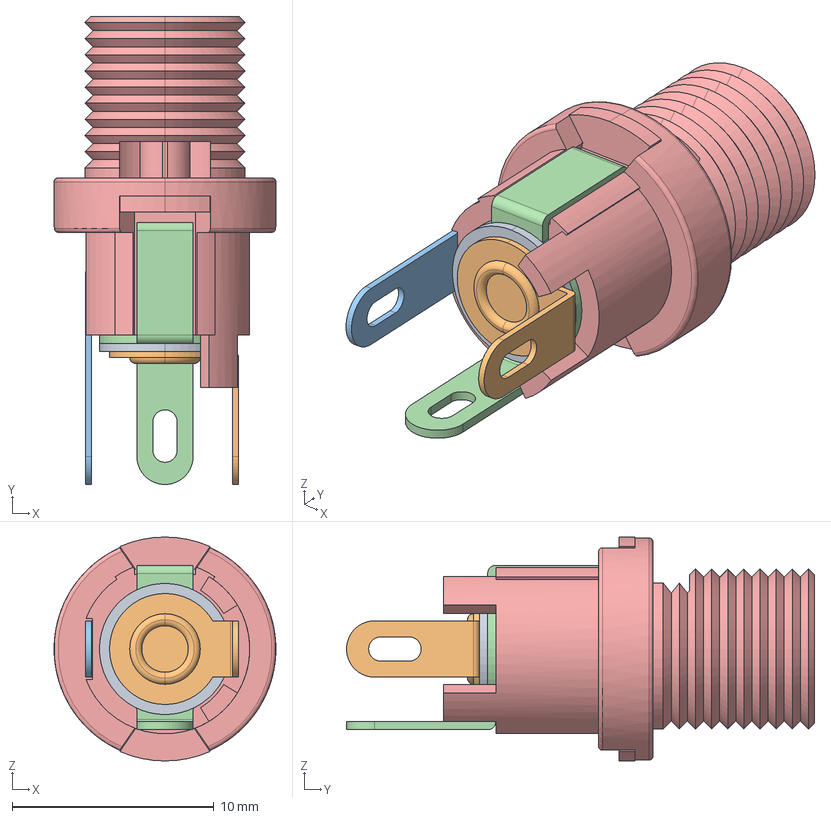
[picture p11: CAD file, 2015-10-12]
KiCad/datasheets/pj-065b.stp
11.0 x 23.2 x 11.1 mm

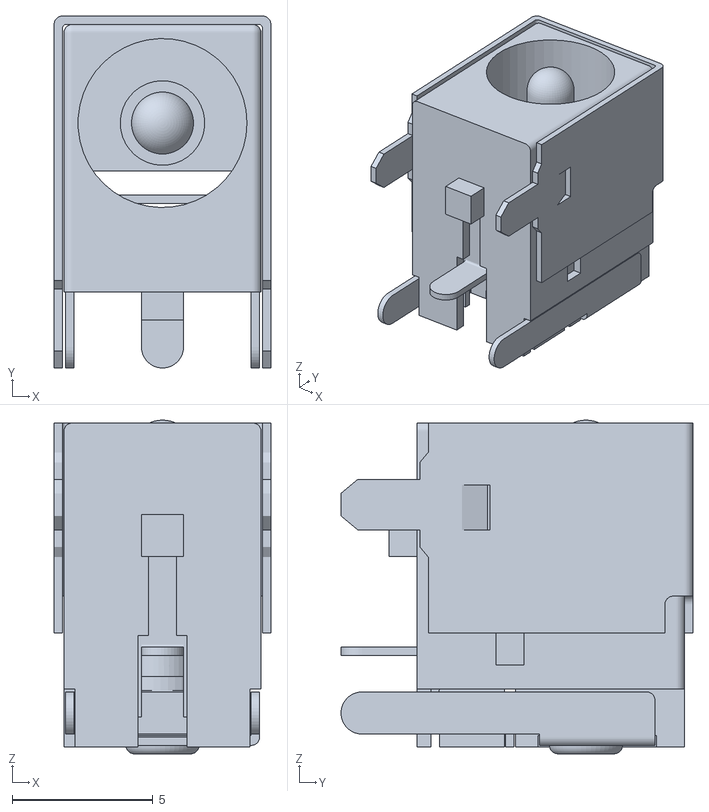
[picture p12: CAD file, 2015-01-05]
KiCad_bak/3d_modules/Barrel_Socket_STL_PJ-047B.stl
7.70 x 12.5 x 11.9

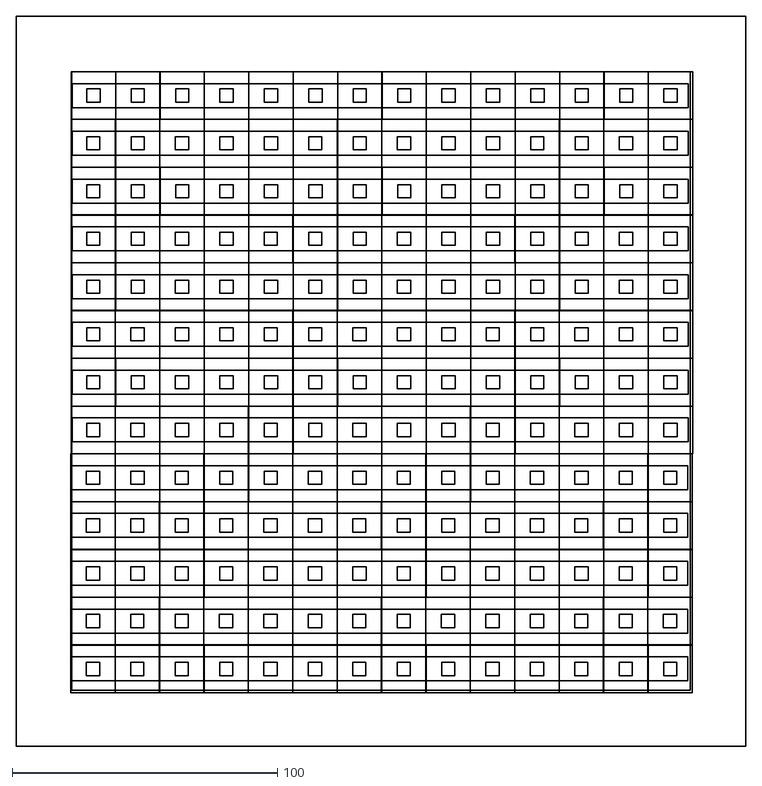
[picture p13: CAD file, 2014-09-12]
fabricate/30x30 size/output/Ready to print/backplate guide.dxf
275.0 x 275.0

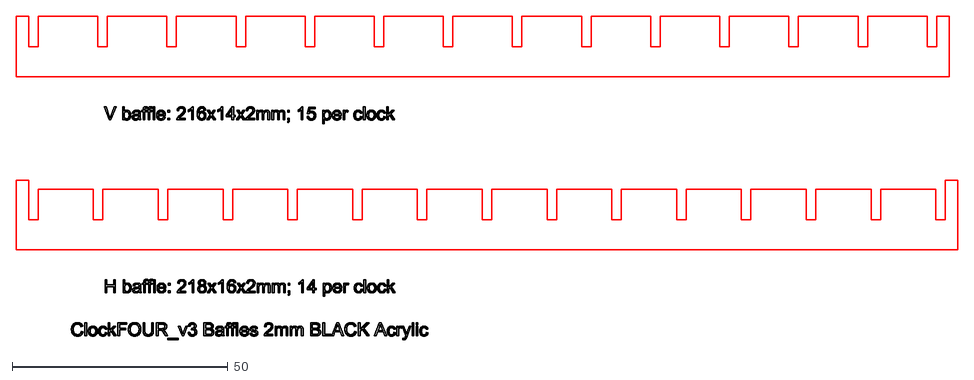
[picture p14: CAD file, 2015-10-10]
fabricate/ClockFOUR_Chronogram_v3.0/output/LASER/baffles_C4_v3.0.dxf
218.0 x 74.9

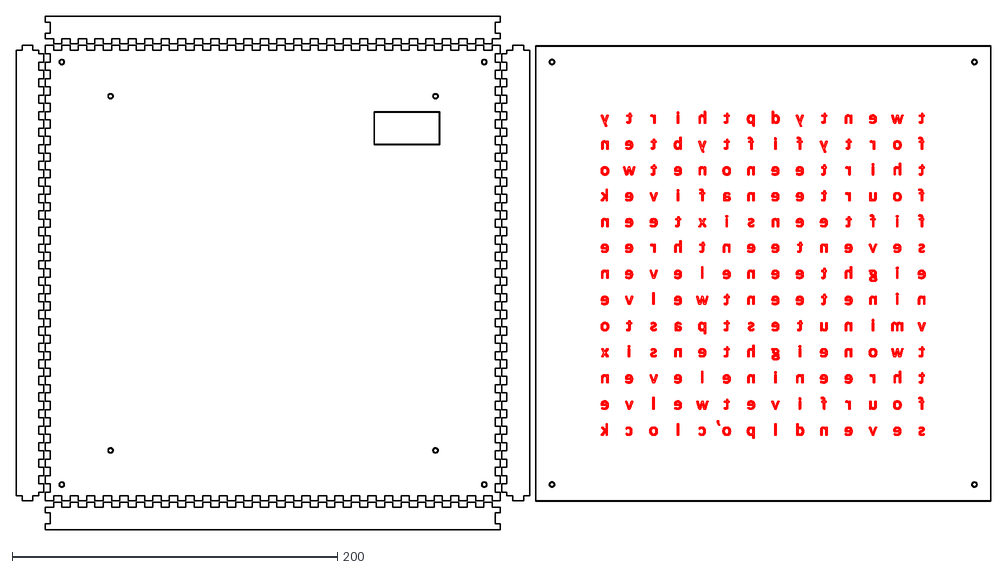
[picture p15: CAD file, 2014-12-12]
fabricate/ClockFOUR_v1/output/ClockFOUR_v1_first try.dxf
599.9 x 316.0

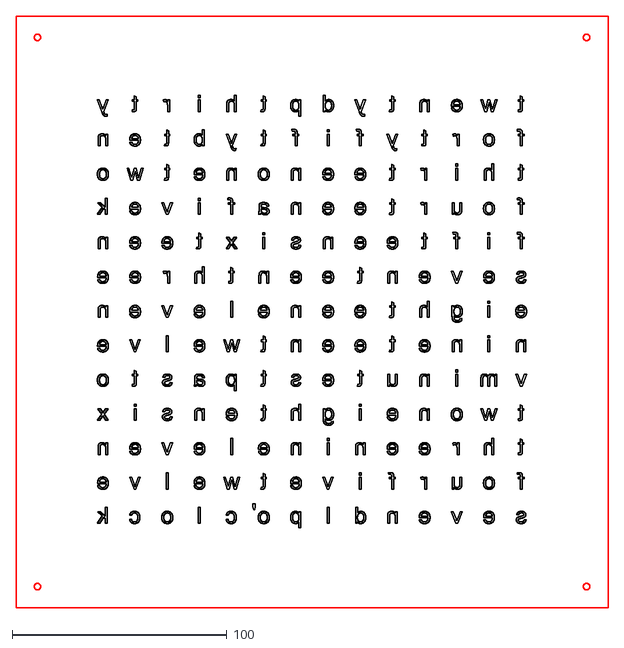
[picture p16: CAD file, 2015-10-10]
fabricate/ClockFOUR_Chronogram_v3.0/output/LASER/english_lower_FINAL Helvetica_C4_v3.0.dxf
276.0 x 276.0

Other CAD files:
KiCad_bak/3D_Render/c4.fcstd
KiCad_bak/3d_modules/Barrel_Socket_STL_PJ-047A.stl
KiCad_bak/archived/C4_rev1/3d_modules/Barrel_Socket_STL_PJ-047A.stl
fabricate/Power_Socket_Bracket/C4_bracket.stl

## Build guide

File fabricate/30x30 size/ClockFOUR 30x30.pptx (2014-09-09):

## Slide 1

60 per meter WS2811B

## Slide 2

11x10

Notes: Canvas 295 ^2
Glass 275 ^2
Viewable glass (in frame) 265 ^2

LED’s 60 / meter WS2811B pixel strips (non waterproof)
Matrix 11 x 10

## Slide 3

12x10

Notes: Canvas 295 ^2
Glass 275 ^2
Viewable glass (in frame) 265 ^2

LED’s 60 / meter WS2811B pixel strips (non waterproof)
Matrix 12 x 10

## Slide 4

12x11

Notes: Canvas 295 ^2
Glass 275 ^2
Viewable glass (in frame) 265 ^2

LED’s 60 / meter WS2811B pixel strips (non waterproof)
Matrix 12 x 11

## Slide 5

14x13

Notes: Canvas 295 ^2
Glass 275 ^2
Viewable glass (in frame) 265 ^2

LED’s 60 / meter WS2811B pixel strips (non waterproof)
Matrix XX x YY

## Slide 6

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
14x13

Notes: Canvas 295 ^2
Glass 275 ^2
Viewable glass (in frame) 265 ^2

LED’s 60 / meter WS2811B pixel strips (non waterproof)
Matrix XX x YY

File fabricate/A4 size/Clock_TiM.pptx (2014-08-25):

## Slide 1

18.29 cm

21.34 cm

30.48 cm

33.39 cm

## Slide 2

18.29 cm

30.48 cm

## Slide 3

18.29 cm

21.34 cm

30.48 cm

33.39 cm

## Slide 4

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
18.29 cm

21.34 cm

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
30.48 cm

33.39 cm

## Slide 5

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
18.29 cm

7.2 in

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
30.48 cm

12 in

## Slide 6

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
18.29 cm

7.2 in

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
30.48 cm

12 in

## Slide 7

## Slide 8

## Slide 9

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
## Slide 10

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
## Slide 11

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
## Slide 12

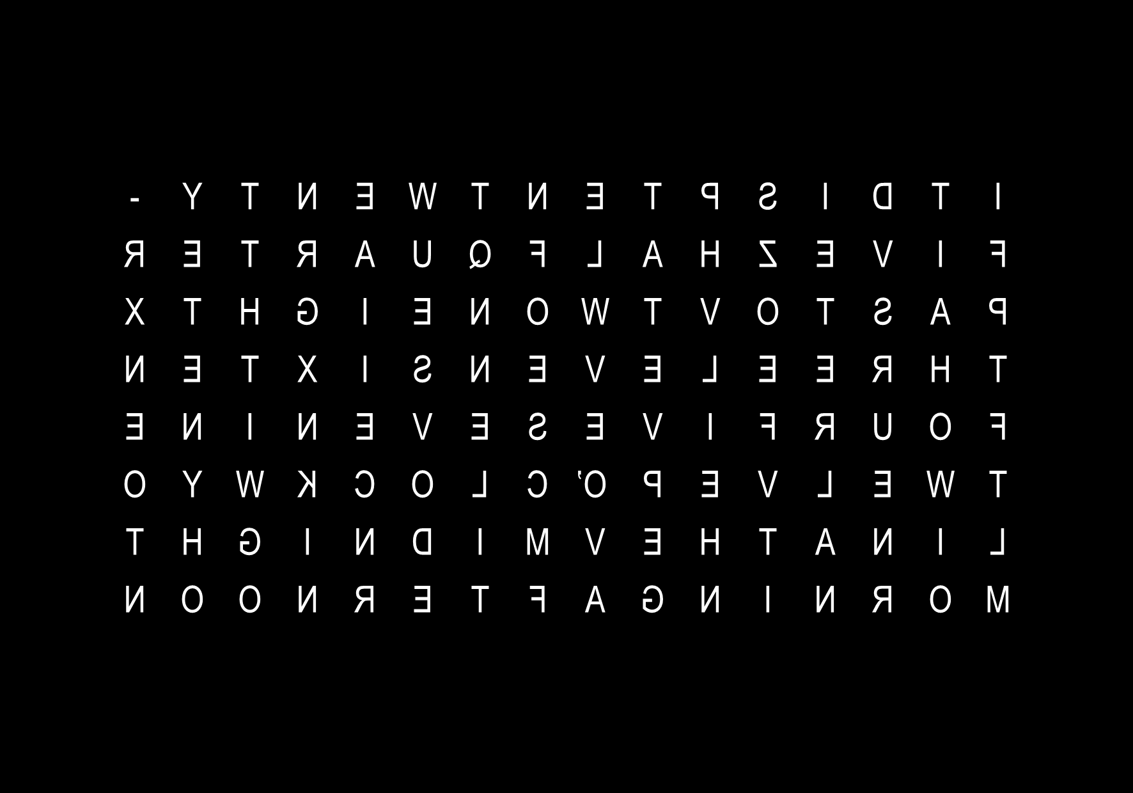
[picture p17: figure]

The black vinyl sheet area is 210 x 300 mm
Cutting area is 120 x 240 mm – white letters (blanks) removed

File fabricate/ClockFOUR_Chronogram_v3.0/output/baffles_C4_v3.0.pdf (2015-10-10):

ClockFOUR baffles C4_v3.0

Localizer: Rout=4mm, Rin=1.5mm; 12 per clock

H baffle: 218x16x2mm; 14 per clock

V baffle: 216x14x2mm; 15 per clock

ClockFOUR_v3 Baffles 2mm BLACK Acrylic

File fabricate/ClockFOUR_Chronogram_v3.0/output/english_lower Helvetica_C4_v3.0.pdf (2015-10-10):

english_lower Helvetica C4_v3.0 276x276x3mm

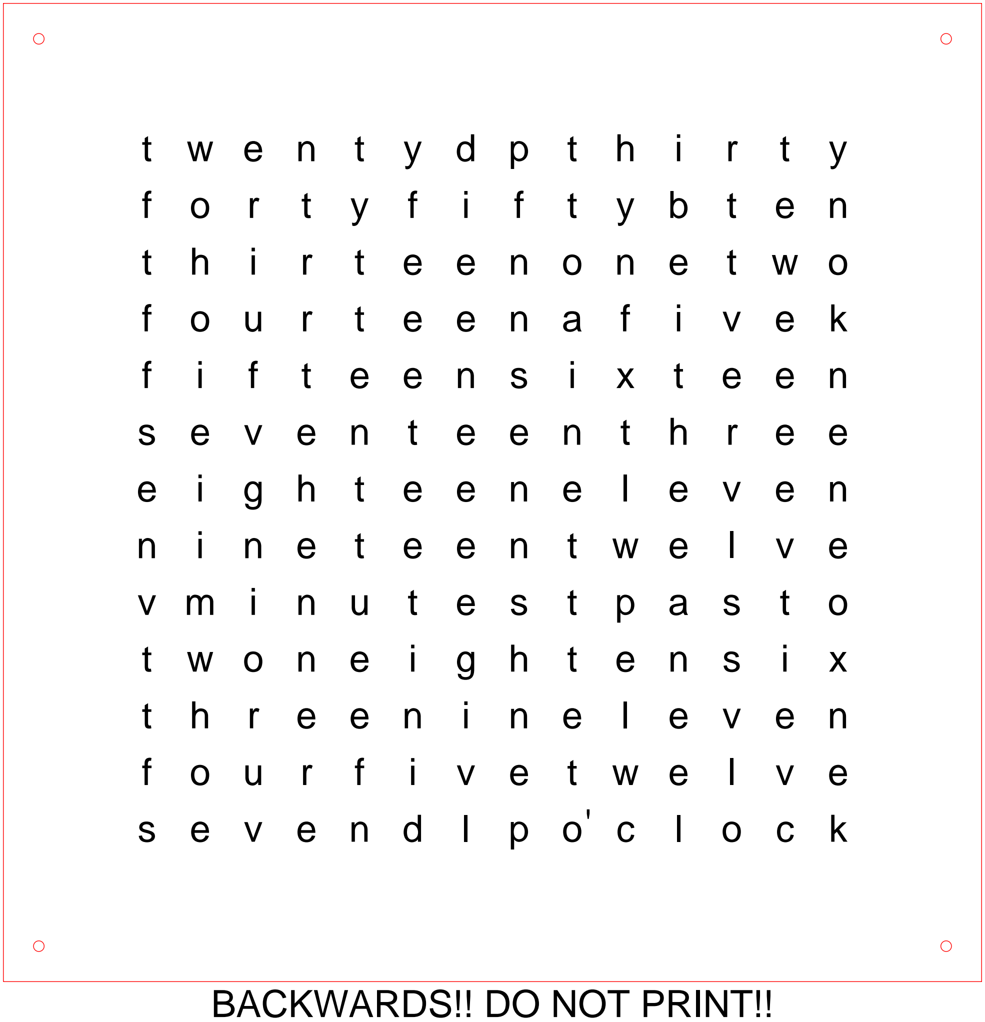
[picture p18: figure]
BACKWARDS!! DO NOT PRINT!!

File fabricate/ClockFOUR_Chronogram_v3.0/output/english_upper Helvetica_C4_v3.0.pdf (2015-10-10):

english_upper Helvetica C4_v3.0 276x276x3mm

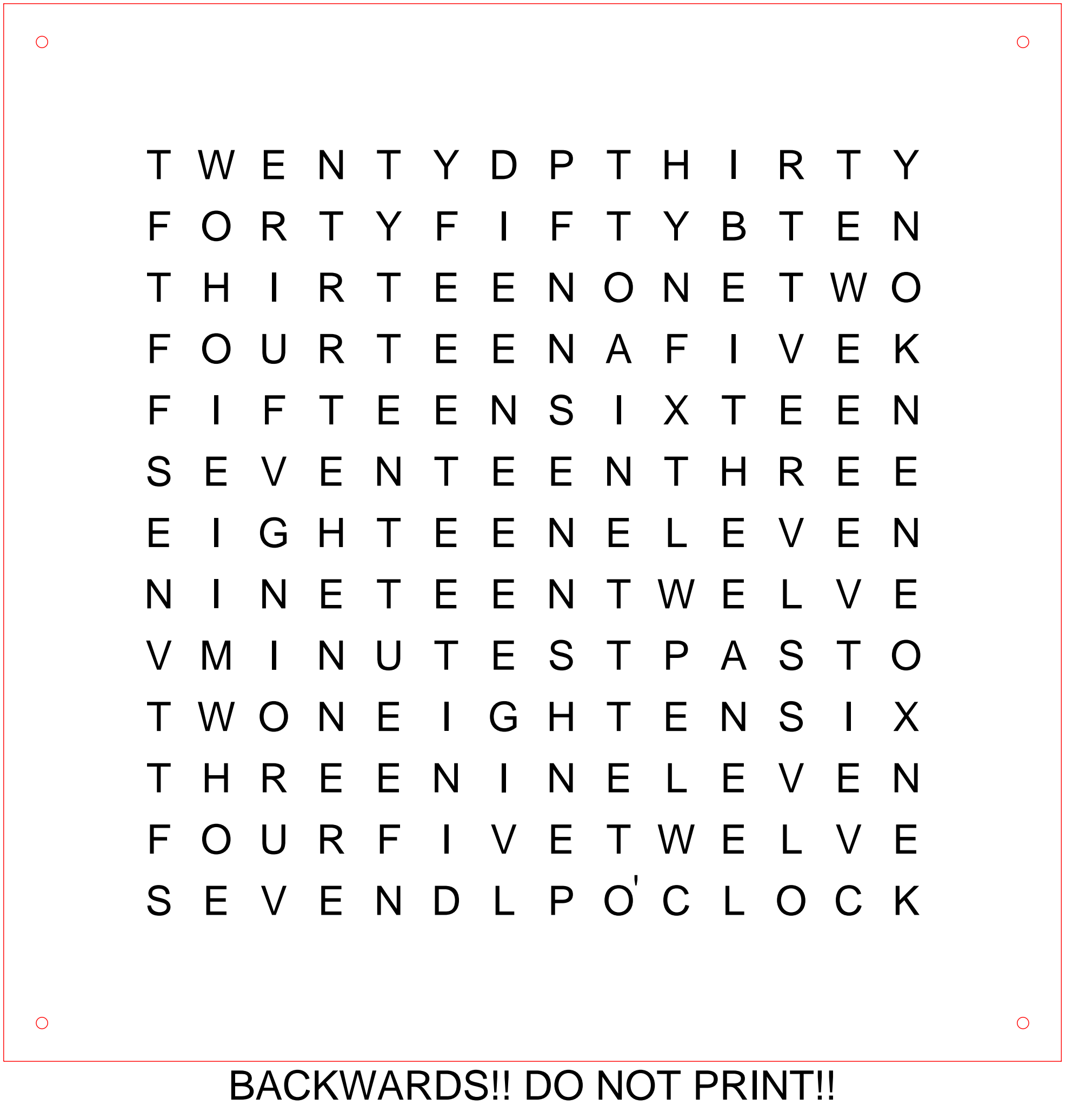
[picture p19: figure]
BACKWARDS!! DO NOT PRINT!!

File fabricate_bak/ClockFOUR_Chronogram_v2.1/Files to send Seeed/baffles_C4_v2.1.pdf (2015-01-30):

ClockFOUR baffles and sides C4_v2.1

Localizer: Rout=4mm, Rin=1.5mm; 12 per clock

H baffle: 218x16x2mm; 14 per clock

V baffle: 216x14x2mm; 15 per clock

ClockFOUR_v2 Baffles 2mm BLACK Acrylic

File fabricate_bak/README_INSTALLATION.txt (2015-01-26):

To create and modify mechanical components for ClockFOUR/Chronogram please install the following pieces of software:

Install Python 2.7x
https://www.python.org/downloads/release/python-279/

PIL for Python 2.7
http://www.pythonware.com/products/pil/

Reportlab for Python 2.7
https://bitbucket.org/rptlab/reportlab

Numpy for Python 2.7
http://sourceforge.net/projects/numpy/files/NumPy/1.9.1/

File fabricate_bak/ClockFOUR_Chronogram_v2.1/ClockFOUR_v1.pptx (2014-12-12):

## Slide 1

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
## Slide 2

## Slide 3

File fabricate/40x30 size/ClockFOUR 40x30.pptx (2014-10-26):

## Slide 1

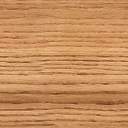
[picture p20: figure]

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
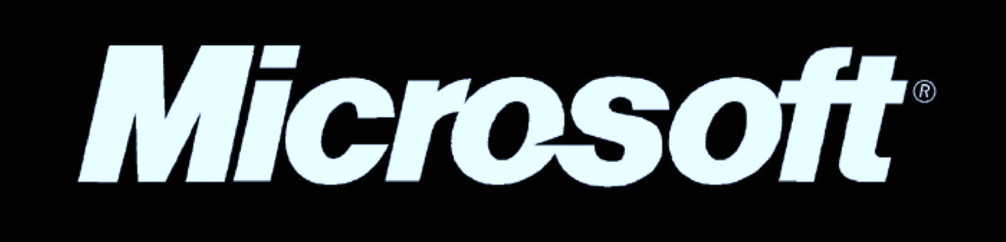
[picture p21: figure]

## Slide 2

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
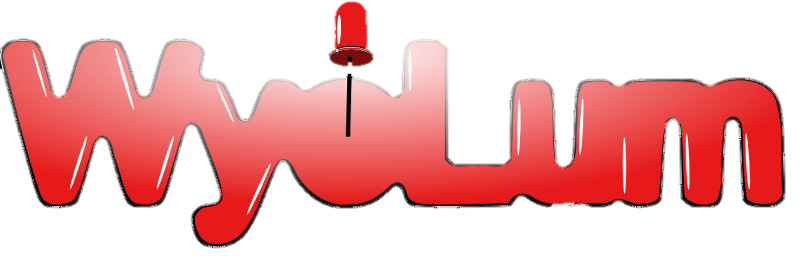
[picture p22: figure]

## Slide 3

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
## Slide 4

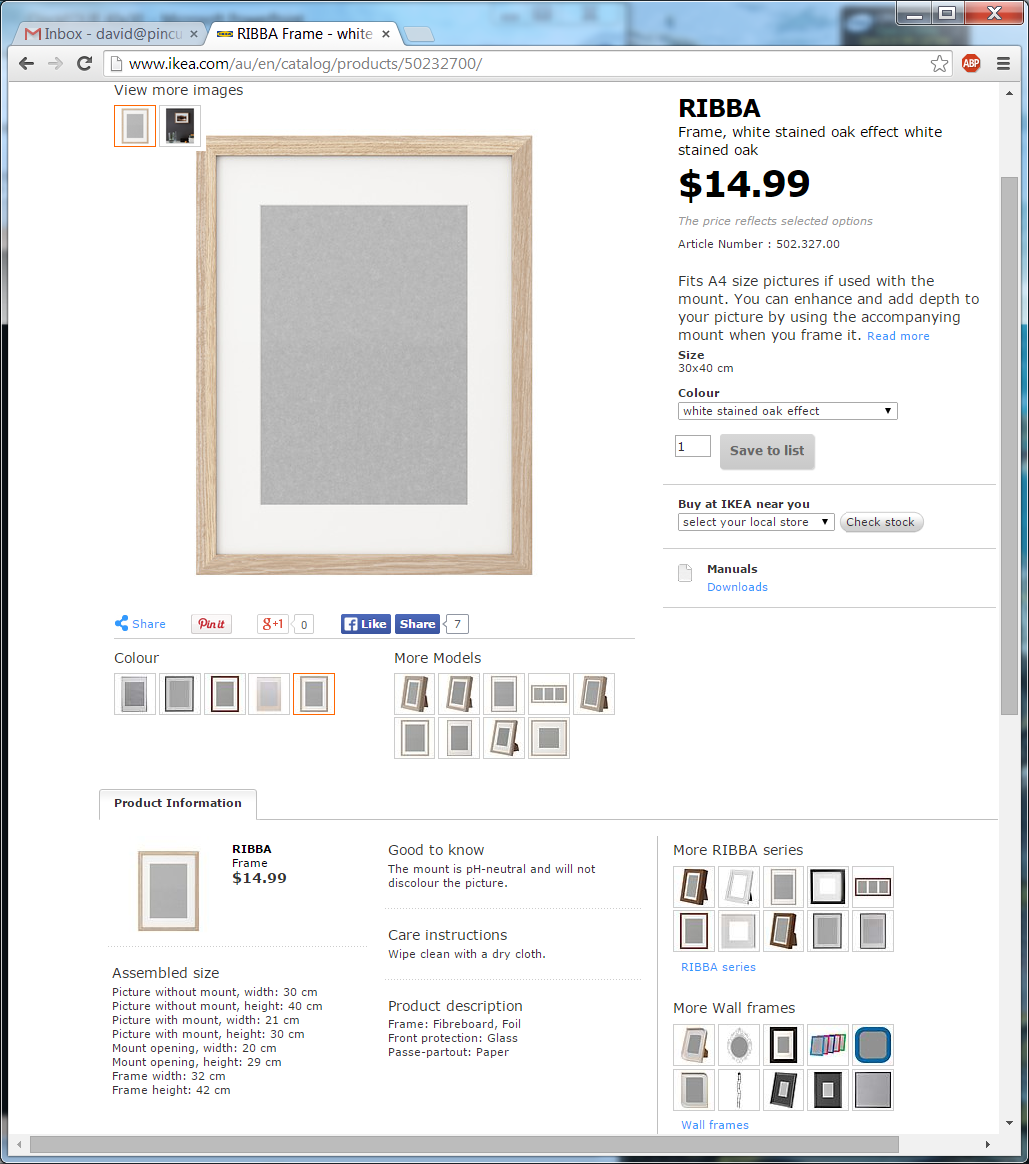
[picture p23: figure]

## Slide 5

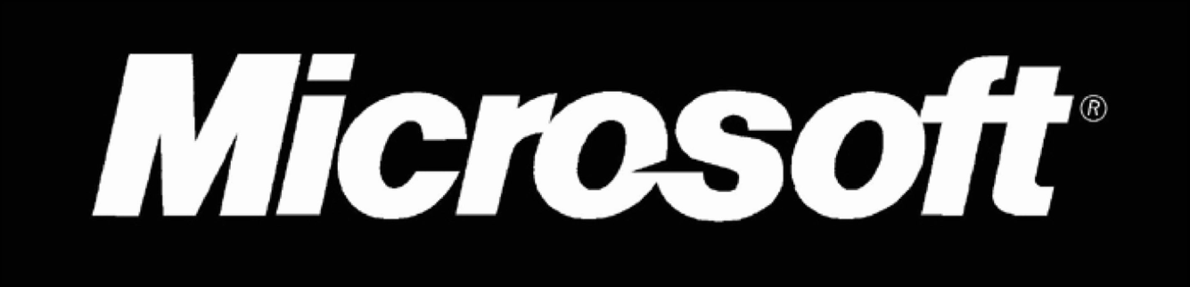
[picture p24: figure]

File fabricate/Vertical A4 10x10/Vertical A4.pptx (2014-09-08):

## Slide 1

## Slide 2

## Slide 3

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
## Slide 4

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
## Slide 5

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
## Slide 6

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
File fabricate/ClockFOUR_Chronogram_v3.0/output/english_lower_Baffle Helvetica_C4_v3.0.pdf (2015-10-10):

english_lower_Baffle Helvetica C4_v3.0 276x276x3mm

BACKWARDS!! DO NOT PRINT!!

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

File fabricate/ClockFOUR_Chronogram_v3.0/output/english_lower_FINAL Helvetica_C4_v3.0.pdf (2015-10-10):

english_lower_FINAL Helvetica C4_v3.0 276x276x3mm

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

'
o p l d n e v e s

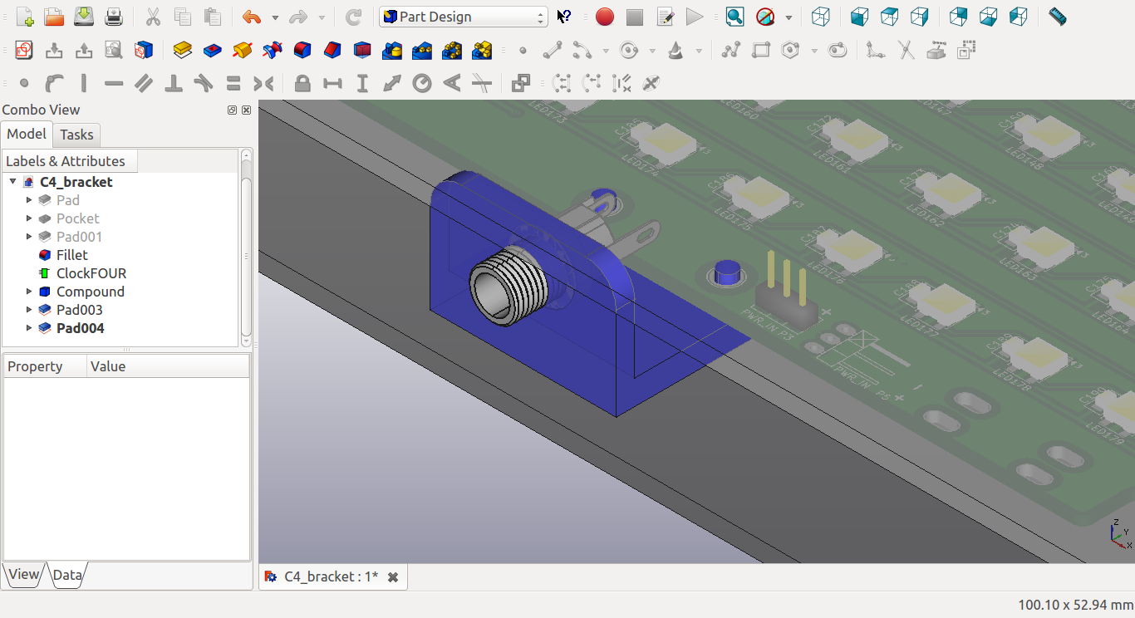
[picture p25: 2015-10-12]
fabricate/Power_Socket_Bracket/C4_bracket_01.png

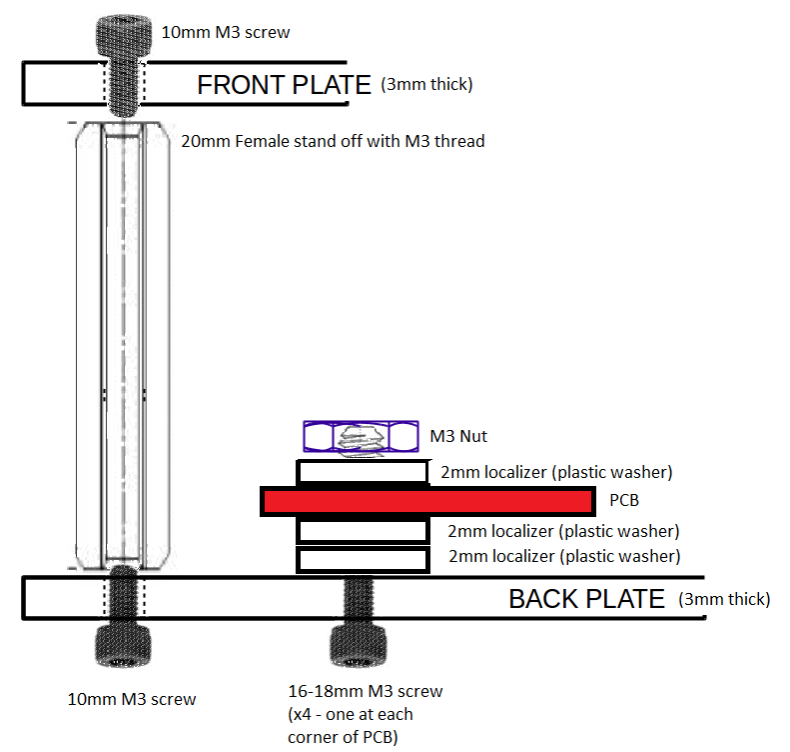
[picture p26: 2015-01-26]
fabricate_bak/ClockFOUR_Chronogram_v2.1/C4 assembly diagram.png

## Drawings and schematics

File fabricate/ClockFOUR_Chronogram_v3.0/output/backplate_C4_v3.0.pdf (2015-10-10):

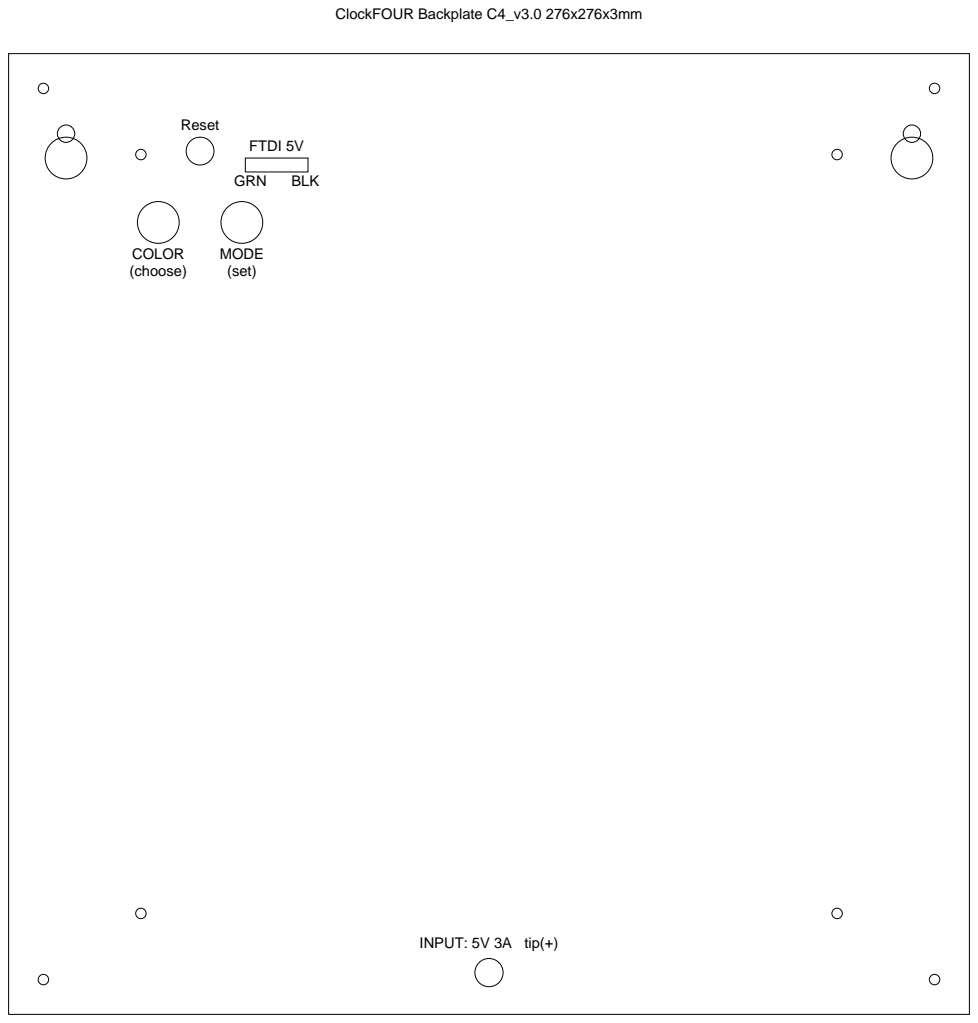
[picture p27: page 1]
ClockFOUR Backplate C4_v3.0 276x276x3mm; Reset; FTDI 5V; GRN; BLK; COLOR (choose); MODE (set); INPUT: 5V 3A tip(+)

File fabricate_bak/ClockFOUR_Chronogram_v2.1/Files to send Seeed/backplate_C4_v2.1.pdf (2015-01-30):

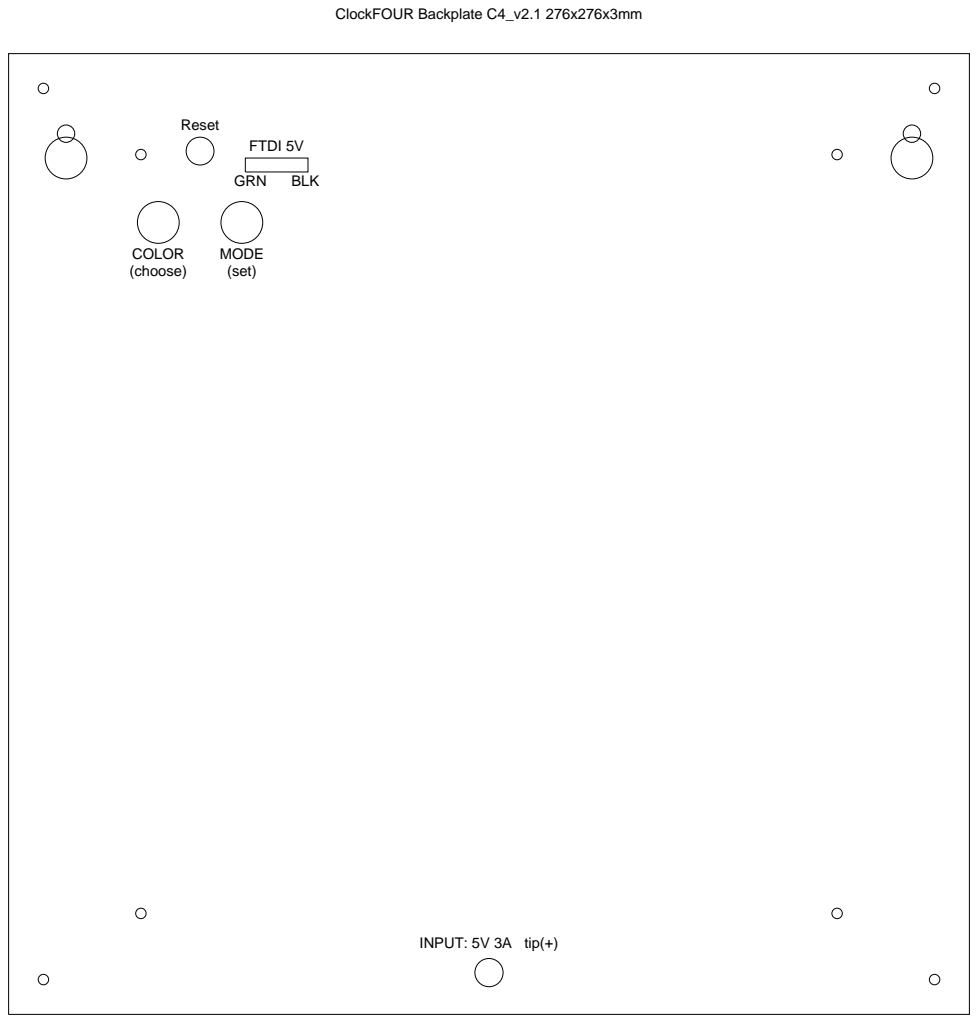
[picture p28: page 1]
ClockFOUR Backplate C4_v2.1 276x276x3mm; Reset; FTDI 5V; GRN; BLK; COLOR (choose); MODE (set); INPUT: 5V 3A tip(+)

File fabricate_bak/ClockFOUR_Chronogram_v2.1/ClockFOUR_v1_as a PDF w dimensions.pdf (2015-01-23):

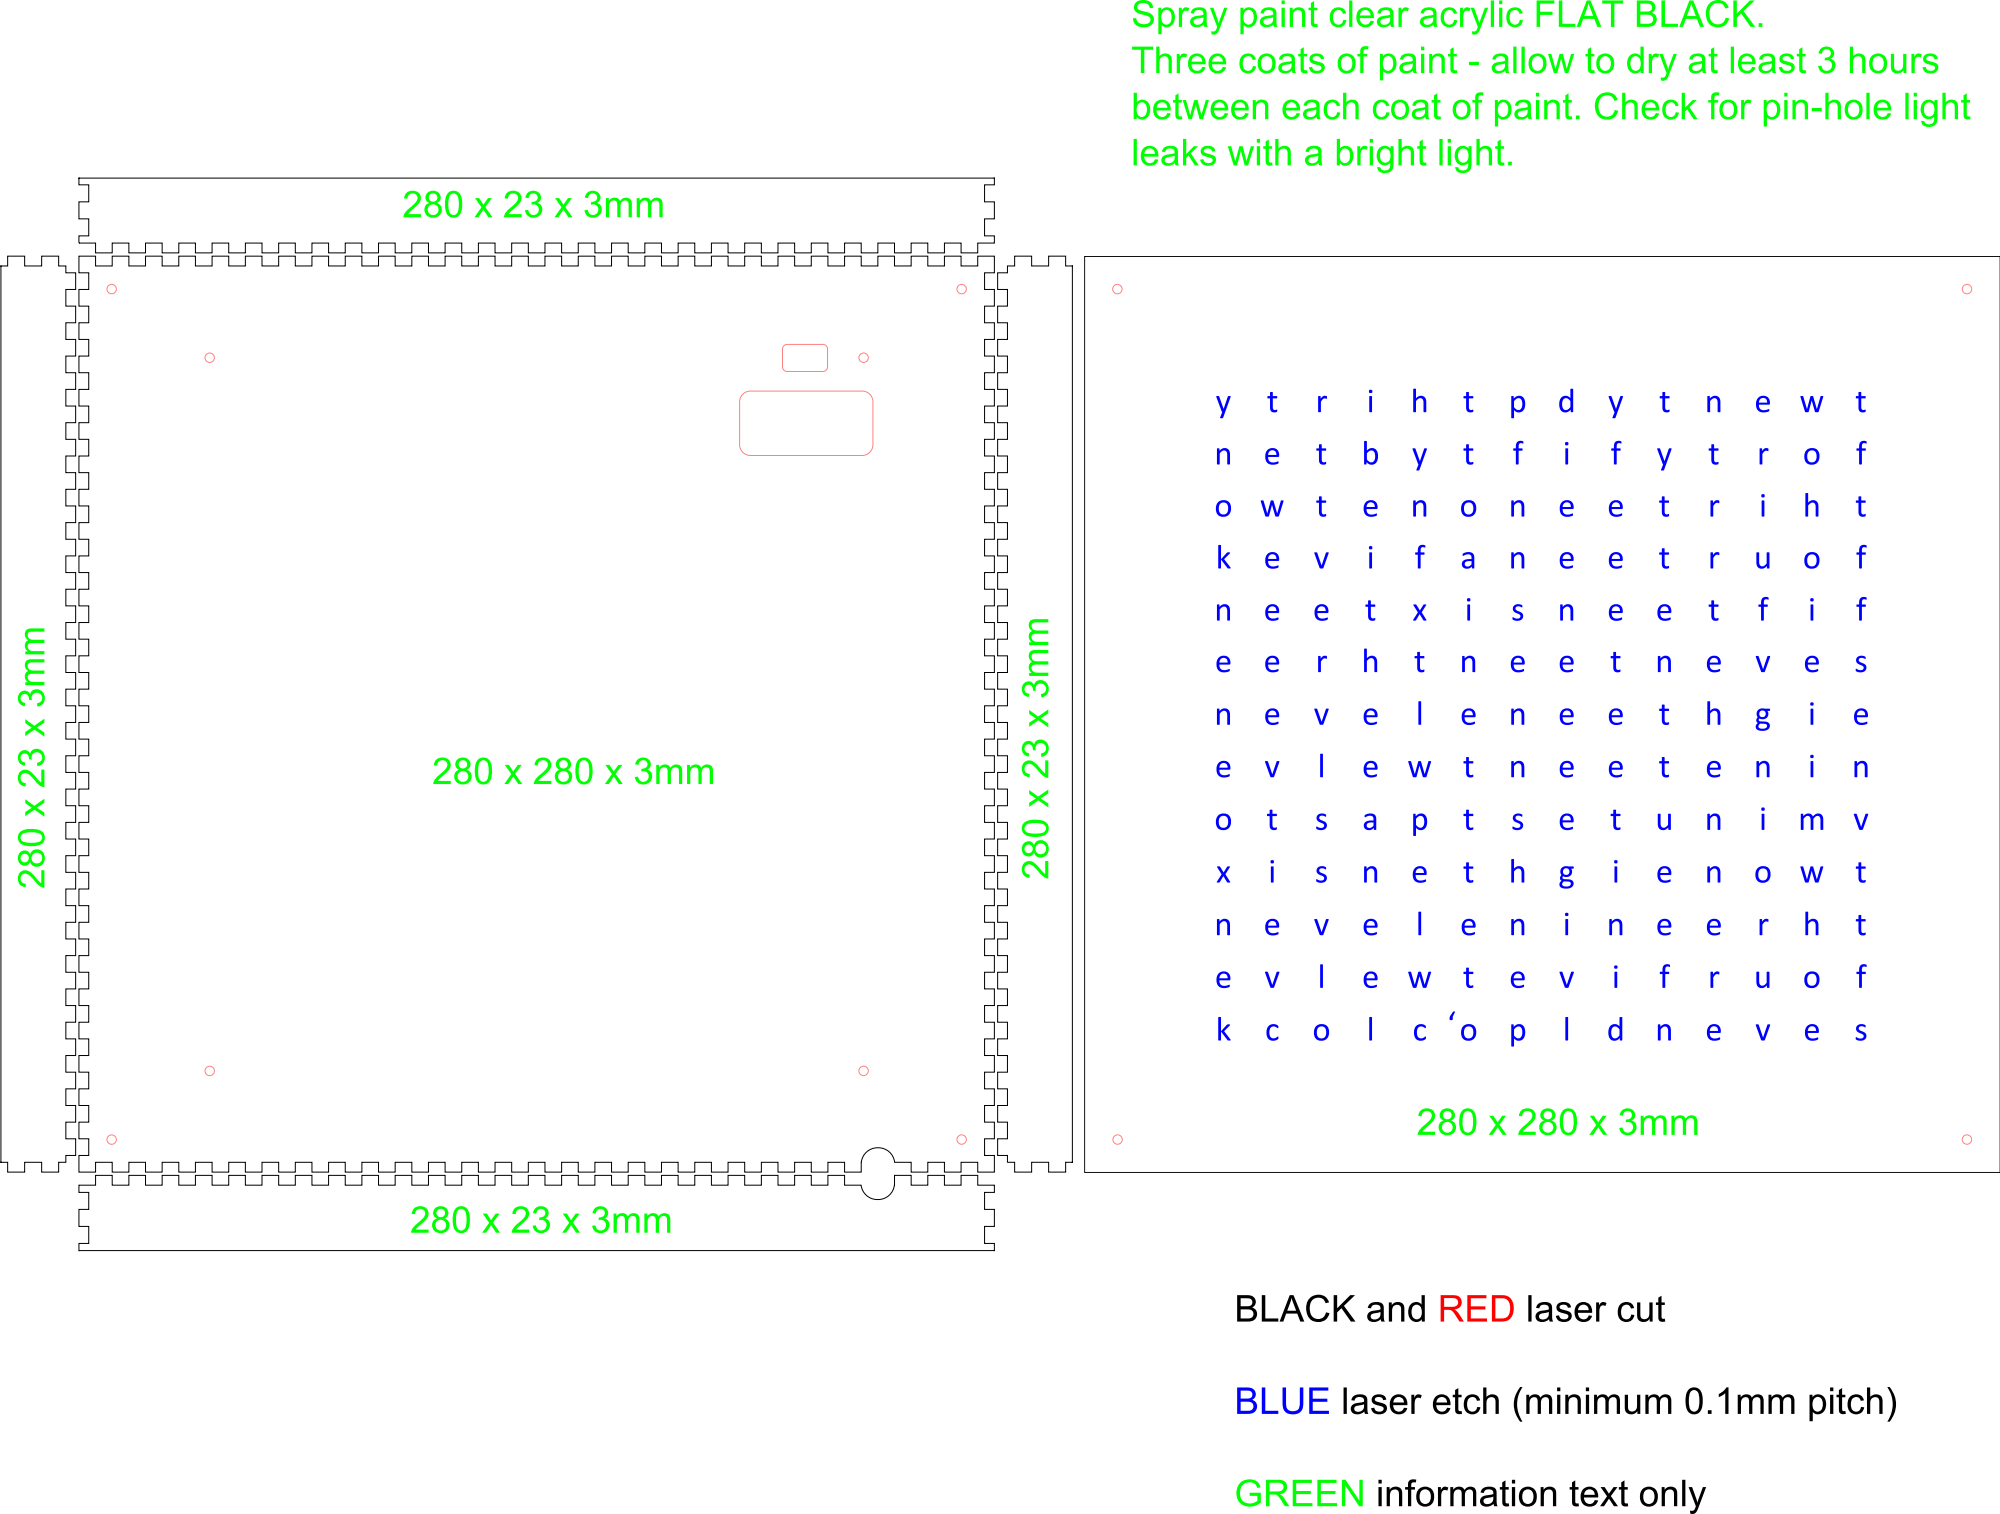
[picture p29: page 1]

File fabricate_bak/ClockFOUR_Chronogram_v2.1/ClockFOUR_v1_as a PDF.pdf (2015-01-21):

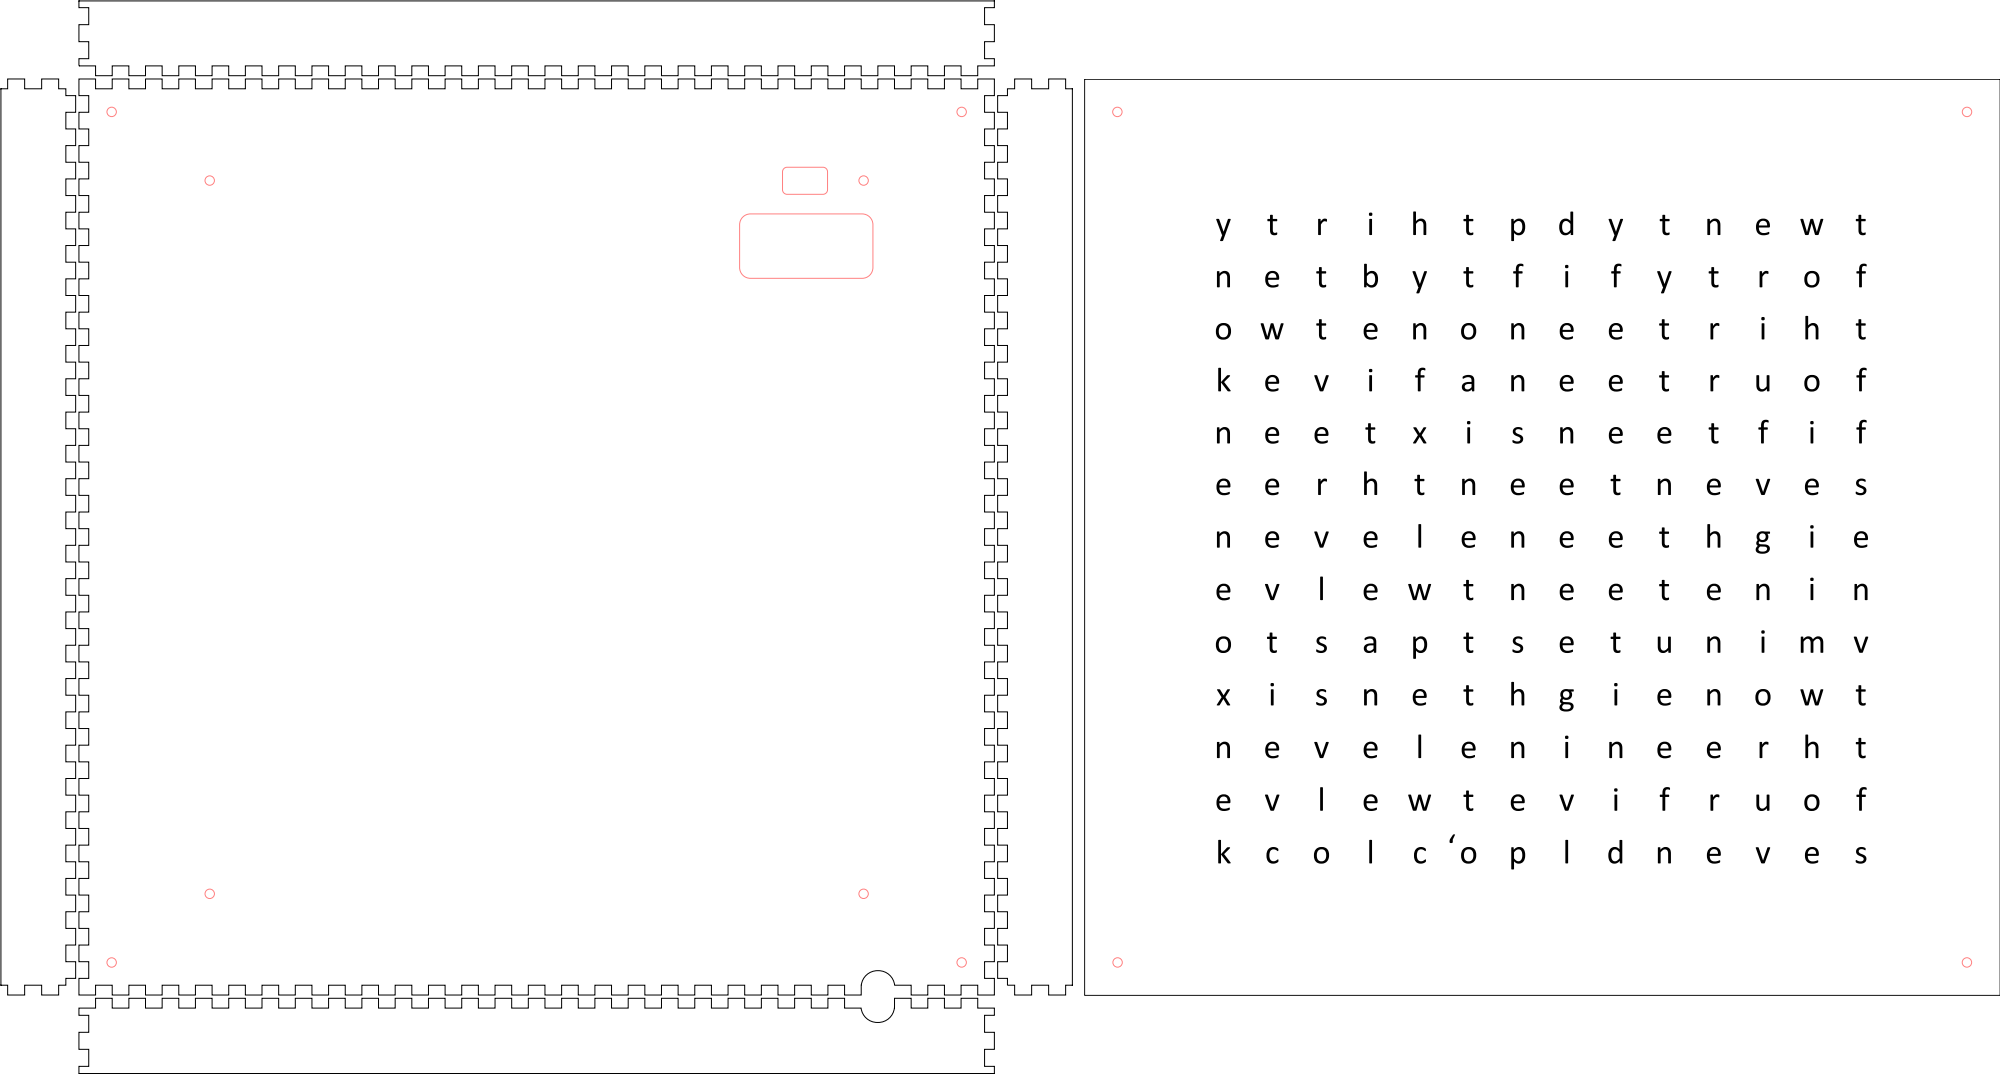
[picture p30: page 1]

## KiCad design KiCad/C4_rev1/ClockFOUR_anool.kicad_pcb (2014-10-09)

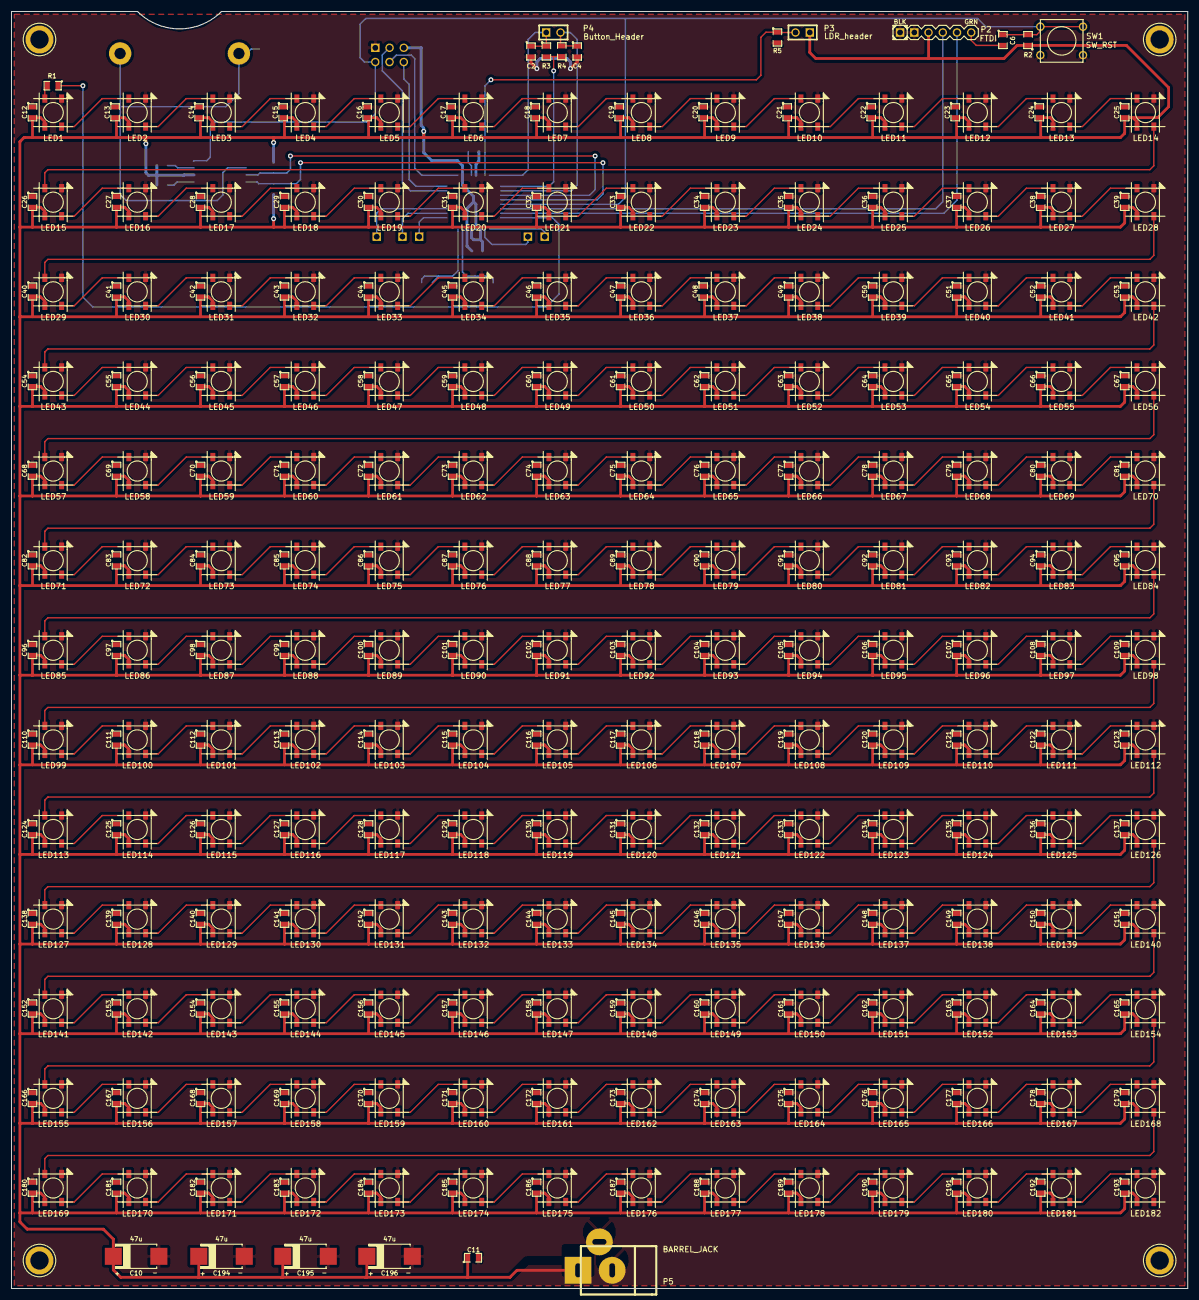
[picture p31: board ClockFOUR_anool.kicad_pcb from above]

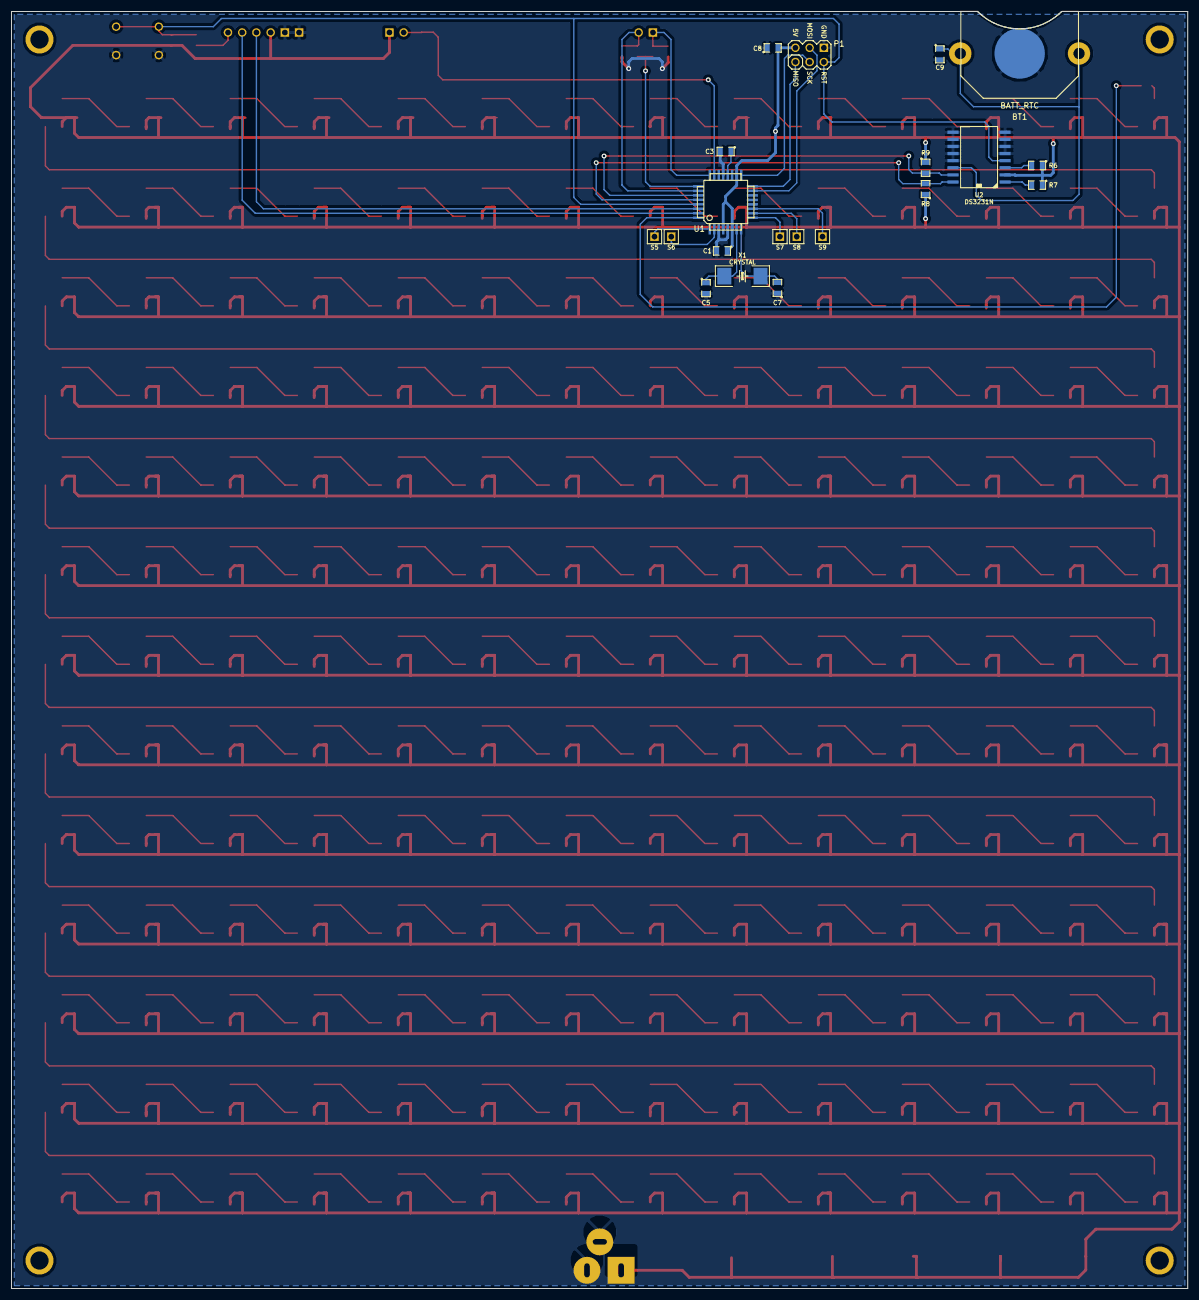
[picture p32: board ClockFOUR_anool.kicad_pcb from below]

Board: 2 copper layers, 210.0 x 228.0 mm, 406 parts (20 on the bottom side), 209 nets.

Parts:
BT1: BATT_RTC; CR2032
C1, C3, C6, C8, C9, C11: 100n; SM0805
C2, C4: 100p; SM0805
C5, C7: 22p; SM0805
C10, C194, C195, C196: 47u; c_2917
C12, C13, C14, C15, C16, C17, C18, C19, C20, C21, C22, C23, C24, C25, C26, C27, C28, C29, C30, C31, C32, C33, C34, C35, C36, C37, C38, C39, C40, C41, C42, C43, C44, C45, C46, C47, C48, C49, C50, C51, C52, C53, C54, C55, C56, C57, C58, C59, C60, C61, C62, C63, C64, C65, C66, C67, C68, C69, C70, C71, C72, C73, C74, C75, C76, C77, C78, C79, C80, C81, C82, C83, C84, C85, C86, C87, C88, C89, C90, C91, C92, C93, C94, C95, C96, C97, C98, C99, C100, C101, C102, C103, C104, C105, C106, C107, C108, C109, C110, C111, C112, C113, C114, C115, C116, C117, C118, C119, C120, C121, C122, C123, C124, C125, C126, C127, C128, C129, C130, C131, C132, C133, C134, C135, C136, C137, C138, C139, C140, C141, C142, C143, C144, C145, C146, C147, C148, C149, C150, C151, C152, C153, C154, C155, C156, C157, C158, C159, C160, C161, C162, C163, C164, C165, C166, C167, C168, C169, C170, C171, C172, C173, C174, C175, C176, C177, C178, C179, C180, C181, C182, C183, C184, C185, C186, C187, C188, C189, C190, C191, C192, C193: 100n; C4_SM0805
LED1, LED2, LED3, LED4, LED5, LED6, LED7, LED8, LED9, LED10, LED11, LED12, LED13, LED14, LED15, LED16, LED17, LED18, LED19, LED20, LED21, LED22, LED23, LED24, LED25, LED26, LED27, LED28, LED29, LED30, LED31, LED32, LED33, LED34, LED35, LED36, LED37, LED38, LED39, LED40, LED41, LED42, LED43, LED44, LED45, LED46, LED47, LED48, LED49, LED50, LED51, LED52, LED53, LED54, LED55, LED56, LED57, LED58, LED59, LED60, LED61, LED62, LED63, LED64, LED65, LED66, LED67, LED68, LED69, LED70, LED71, LED72, LED73, LED74, LED75, LED76, LED77, LED78, LED79, LED80, LED81, LED82, LED83, LED84, LED85, LED86, LED87, LED88, LED89, LED90, LED91, LED92, LED93, LED94, LED95, LED96, LED97, LED98, LED99, LED100, LED101, LED102, LED103, LED104, LED105, LED106, LED107, LED108, LED109, LED110, LED111, LED112, LED113, LED114, LED115, LED116, LED117, LED118, LED119, LED120, LED121, LED122, LED123, LED124, LED125, LED126, LED127, LED128, LED129, LED130, LED131, LED132, LED133, LED134, LED135, LED136, LED137, LED138, LED139, LED140, LED141, LED142, LED143, LED144, LED145, LED146, LED147, LED148, LED149, LED150, LED151, LED152, LED153, LED154, LED155, LED156, LED157, LED158, LED159, LED160, LED161, LED162, LED163, LED164, LED165, LED166, LED167, LED168, LED169, LED170, LED171, LED172, LED173, LED174, LED175, LED176, LED177, LED178, LED179, LED180, LED181, LED182: WS2812B
P1: ICSP; Header_ISP
P2: FTDI; Header_FTDI
P3: LDR_header; SIL-2
P4: Button_Header; SIL-2
P5: BARREL_JACK; JACK_ALIM
R1: 500R; SM0805
R2, R5, R6, R7: 10K; SM0805
R3, R4: 1M; SM0805
R8, R9: 4K7; SM0805
S1, S2, S3, S4: CONN_1; 1pin
S5, S6, S7, S8, S9: CONN_1; PIN_ARRAY_1
SW1: SW_RST; SW_PUSH_SMALL
U1: ATMEGA328P; TQFP32
U2: DS3231N; DS3231
X1: CRYSTAL; Xtal_SMD

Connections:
5V: C1.1, C8.2, C10.1, C11.1, C12.2, C13.2, C14.2, C15.2, C16.2, C17.2, C18.2, C19.2, C20.2, C21.2, C22.2, C23.2, C24.2, C25.2, C26.2, C27.2, C28.2, C29.2, C30.2, C31.2, C32.2, C33.2, C34.2, C35.2, C36.2, C37.2, C38.2, C39.2, C40.2, C41.2, C42.2, C43.2, C44.2, C45.2, C46.2, C47.2, C48.2, C49.2, C50.2, C51.2, C52.2, C53.2, C54.2, C55.2, C56.2, C57.2, C58.2, C59.2, C60.2, C61.2, C62.2, C63.2, C64.2, C65.2, C66.2, C67.2, C68.2, C69.2, C70.2, C71.2, C72.2, C73.2, C74.2, C75.2, C76.2, C77.2, C78.2, C79.2, C80.2, C81.2, C82.2, C83.2, C84.2, C85.2, C86.2, C87.2, C88.2, C89.2, C90.2, C91.2, C92.2, C93.2, C94.2, C95.2, C96.2, C97.2, C98.2, C99.2, C100.2, C101.2, C102.2, C103.2, C104.2, C105.2, C106.2, C107.2, C108.2, C109.2, C110.2, C111.2, C112.2, C113.2, C114.2, C115.2, C116.2, C117.2, C118.2, C119.2, C120.2, C121.2, C122.2, C123.2, C124.2, C125.2, C126.2, C127.2, C128.2, C129.2, C130.2, C131.2, C132.2, C133.2, C134.2, C135.2, C136.2, C137.2, C138.2, C139.2, C140.2, C141.2, C142.2, C143.2, C144.2, C145.2, C146.2, C147.2, C148.2, C149.2, C150.2, C151.2, C152.2, C153.2, C154.2, C155.2, C156.2, C157.2, C158.2, C159.2, C160.2, C161.2, C162.2, C163.2, C164.2, C165.2, C166.2, C167.2, C168.2, C169.2, C170.2, C171.2, C172.2, C173.2, C174.2, C175.2, C176.2, C177.2, C178.2, C179.2, C180.2, C181.2, C182.2, C183.2, C184.2, C185.2, C186.2, C187.2, C188.2, C189.2, C190.2, C191.2, C192.2, C193.2, C194.1, C195.1, C196.1, LED1.1, LED2.1, LED3.1, LED4.1, LED5.1, LED6.1, LED7.1, LED8.1, LED9.1, LED10.1, LED11.1, LED12.1, LED13.1, LED14.1, LED15.1, LED16.1, LED17.1, LED18.1, LED19.1, LED20.1, LED21.1, LED22.1, LED23.1, LED24.1, LED25.1, LED26.1, LED27.1, LED28.1, LED29.1, LED30.1, LED31.1, LED32.1, LED33.1, LED34.1, LED35.1, LED36.1, LED37.1, LED38.1, LED39.1, LED40.1, LED41.1, LED42.1, LED43.1, LED44.1, LED45.1, LED46.1, LED47.1, LED48.1, LED49.1, LED50.1, LED51.1, LED52.1, LED53.1, LED54.1, LED55.1, LED56.1, LED57.1, LED58.1, LED59.1, LED60.1, LED61.1, LED62.1, LED63.1, LED64.1, LED65.1, LED66.1, LED67.1, LED68.1, LED69.1, LED70.1, LED71.1, LED72.1, LED73.1, LED74.1, LED75.1, LED76.1, LED77.1, LED78.1, LED79.1, LED80.1, LED81.1, LED82.1, LED83.1, LED84.1, LED85.1, LED86.1, LED87.1, LED88.1, LED89.1, LED90.1, LED91.1, LED92.1, LED93.1, LED94.1, LED95.1, LED96.1, LED97.1, LED98.1, LED99.1, LED100.1, LED101.1, LED102.1, LED103.1, LED104.1, LED105.1, LED106.1, LED107.1, LED108.1, LED109.1, LED110.1, LED111.1, LED112.1, LED113.1, LED114.1, LED115.1, LED116.1, LED117.1, LED118.1, LED119.1, LED120.1, LED121.1, LED122.1, LED123.1, LED124.1, LED125.1, LED126.1, LED127.1, LED128.1, LED129.1, LED130.1, LED131.1, LED132.1, LED133.1, LED134.1, LED135.1, LED136.1, LED137.1, LED138.1, LED139.1, LED140.1, LED141.1, LED142.1, LED143.1, LED144.1, LED145.1, LED146.1, LED147.1, LED148.1, LED149.1, LED150.1, LED151.1, LED152.1, LED153.1, LED154.1, LED155.1, LED156.1, LED157.1, LED158.1, LED159.1, LED160.1, LED161.1, LED162.1, LED163.1, LED164.1, LED165.1, LED166.1, LED167.1, LED168.1, LED169.1, LED170.1, LED171.1, LED172.1, LED173.1, LED174.1, LED175.1, LED176.1, LED177.1, LED178.1, LED179.1, LED180.1, LED181.1, LED182.1, P1.2, P2.3, P3.1, P5.1, R2.1, R6.1, R7.1, R8.1, R9.1, U1.4, U1.6, U1.18, U2.2
/BUTTON_L: C2.1, P4.1, R3.1, U1.24
/BUTTON_R: C4.1, P4.2, R4.2, U1.26
/D3: S5.1, U1.1
/D4: S6.1, U1.2
/D5: S7.1, U1.9
/D6: S8.1, U1.10
/D7: S9.1, U1.11
/LDR_PIN: P3.2, R5.1, U1.23
/MATRIX_PIN: R1.1, U1.32
/MISO: P1.1, U1.16
/MOSI: P1.4, U1.15
/RESET: C6.1, P1.5, R2.2, SW1.2, U1.29, U2.4
/RXD: P2.4, U1.30
/Row_A/DI_A: LED1.4, R1.2
/Row_B/DI_B: LED14.2, LED15.4
/Row_C/DI_C: LED28.2, LED29.4
/Row_D/DI_D: LED42.2, LED43.4
/Row_E/DI_E: LED56.2, LED57.4
/Row_F/DI_F: LED70.2, LED71.4
/Row_G/DI_G: LED84.2, LED85.4
/Row_H/DI_H: LED98.2, LED99.4
/Row_I/DI_I: LED112.2, LED113.4
/Row_J/DI_J: LED126.2, LED127.4
/Row_K/DI_K: LED140.2, LED141.4
/Row_L/DI_L: LED154.2, LED155.4
/Row_M/DI_M: LED168.2, LED169.4
/SCK: P1.3, U1.17
/SCL: R8.2, U1.28, U2.16
/SDA: R9.2, U1.27, U2.15
/SENSE_PIN: R3.2, R4.1, U1.25
/TXD: P2.5, U1.31
GND: BT1.2, C1.2, C2.2, C3.2, C4.2, C5.2, C7.1, C8.1, C9.2, C10.2, C11.2, C12.1, C13.1, C14.1, C15.1, C16.1, C17.1, C18.1, C19.1, C20.1, C21.1, C22.1, C23.1, C24.1, C25.1, C26.1, C27.1, C28.1, C29.1, C30.1, C31.1, C32.1, C33.1, C34.1, C35.1, C36.1, C37.1, C38.1, C39.1, C40.1, C41.1, C42.1, C43.1, C44.1, C45.1, C46.1, C47.1, C48.1, C49.1, C50.1, C51.1, C52.1, C53.1, C54.1, C55.1, C56.1, C57.1, C58.1, C59.1, C60.1, C61.1, C62.1, C63.1, C64.1, C65.1, C66.1, C67.1, C68.1, C69.1, C70.1, C71.1, C72.1, C73.1, C74.1, C75.1, C76.1, C77.1, C78.1, C79.1, C80.1, C81.1, C82.1, C83.1, C84.1, C85.1, C86.1, C87.1, C88.1, C89.1, C90.1, C91.1, C92.1, C93.1, C94.1, C95.1, C96.1, C97.1, C98.1, C99.1, C100.1, C101.1, C102.1, C103.1, C104.1, C105.1, C106.1, C107.1, C108.1, C109.1, C110.1, C111.1, C112.1, C113.1, C114.1, C115.1, C116.1, C117.1, C118.1, C119.1, C120.1, C121.1, C122.1, C123.1, C124.1, C125.1, C126.1, C127.1, C128.1, C129.1, C130.1, C131.1, C132.1, C133.1, C134.1, C135.1, C136.1, C137.1, C138.1, C139.1, C140.1, C141.1, C142.1, C143.1, C144.1, C145.1, C146.1, C147.1, C148.1, C149.1, C150.1, C151.1, C152.1, C153.1, C154.1, C155.1, C156.1, C157.1, C158.1, C159.1, C160.1, C161.1, C162.1, C163.1, C164.1, C165.1, C166.1, C167.1, C168.1, C169.1, C170.1, C171.1, C172.1, C173.1, C174.1, C175.1, C176.1, C177.1, C178.1, C179.1, C180.1, C181.1, C182.1, C183.1, C184.1, C185.1, C186.1, C187.1, C188.1, C189.1, C190.1, C191.1, C192.1, C193.1, C194.2, C195.2, C196.2, LED1.3, LED2.3, LED3.3, LED4.3, LED5.3, LED6.3, LED7.3, LED8.3, LED9.3, LED10.3, LED11.3, LED12.3, LED13.3, LED14.3, LED15.3, LED16.3, LED17.3, LED18.3, LED19.3, LED20.3, LED21.3, LED22.3, LED23.3, LED24.3, LED25.3, LED26.3, LED27.3, LED28.3, LED29.3, LED30.3, LED31.3, LED32.3, LED33.3, LED34.3, LED35.3, LED36.3, LED37.3, LED38.3, LED39.3, LED40.3, LED41.3, LED42.3, LED43.3, LED44.3, LED45.3, LED46.3, LED47.3, LED48.3, LED49.3, LED50.3, LED51.3, LED52.3, LED53.3, LED54.3, LED55.3, LED56.3, LED57.3, LED58.3, LED59.3, LED60.3, LED61.3, LED62.3, LED63.3, LED64.3, LED65.3, LED66.3, LED67.3, LED68.3, LED69.3, LED70.3, LED71.3, LED72.3, LED73.3, LED74.3, LED75.3, LED76.3, LED77.3, LED78.3, LED79.3, LED80.3, LED81.3, LED82.3, LED83.3, LED84.3, LED85.3, LED86.3, LED87.3, LED88.3, LED89.3, LED90.3, LED91.3, LED92.3, LED93.3, LED94.3, LED95.3, LED96.3, LED97.3, LED98.3, LED99.3, LED100.3, LED101.3, LED102.3, LED103.3, LED104.3, LED105.3, LED106.3, LED107.3, LED108.3, LED109.3, LED110.3, LED111.3, LED112.3, LED113.3, LED114.3, LED115.3, LED116.3, LED117.3, LED118.3, LED119.3, LED120.3, LED121.3, LED122.3, LED123.3, LED124.3, LED125.3, LED126.3, LED127.3, LED128.3, LED129.3, LED130.3, LED131.3, LED132.3, LED133.3, LED134.3, LED135.3, LED136.3, LED137.3, LED138.3, LED139.3, LED140.3, LED141.3, LED142.3, LED143.3, LED144.3, LED145.3, LED146.3, LED147.3, LED148.3, LED149.3, LED150.3, LED151.3, LED152.3, LED153.3, LED154.3, LED155.3, LED156.3, LED157.3, LED158.3, LED159.3, LED160.3, LED161.3, LED162.3, LED163.3, LED164.3, LED165.3, LED166.3, LED167.3, LED168.3, LED169.3, LED170.3, LED171.3, LED172.3, LED173.3, LED174.3, LED175.3, LED176.3, LED177.3, LED178.3, LED179.3, LED180.3, LED181.3, LED182.3, P1.6, P2.1, P2.2, P5.2, P5.3, R5.2, SW1.1, U1.3, U1.5, U1.21, U2.5, U2.6, U2.7, U2.8, U2.9, U2.10, U2.11, U2.12, U2.13
unnamed: C7.2, U1.8, X1.1
unnamed: C5.1, U1.7, X1.2
unnamed: C6.2, P2.6
unnamed: R6.2, U2.3
unnamed: R7.2, U2.1
unnamed: BT1.1, C9.1, U2.14
unnamed: C3.1, U1.20
unnamed: LED10.2, LED11.4
unnamed: LED7.2, LED8.4
unnamed: LED2.2, LED3.4
unnamed: LED8.2, LED9.4
unnamed: LED9.2, LED10.4
unnamed: LED3.2, LED4.4
unnamed: LED11.2, LED12.4
unnamed: LED12.2, LED13.4
unnamed: LED4.2, LED5.4
unnamed: LED13.2, LED14.4
unnamed: LED1.2, LED2.4
unnamed: LED5.2, LED6.4
unnamed: LED6.2, LED7.4
unnamed: LED27.2, LED28.4
unnamed: LED22.2, LED23.4
unnamed: LED23.2, LED24.4
unnamed: LED24.2, LED25.4
unnamed: LED25.2, LED26.4
unnamed: LED26.2, LED27.4
unnamed: LED18.2, LED19.4
unnamed: LED16.2, LED17.4
unnamed: LED17.2, LED18.4
unnamed: LED19.2, LED20.4
unnamed: LED20.2, LED21.4
unnamed: LED21.2, LED22.4
unnamed: LED15.2, LED16.4
unnamed: LED41.2, LED42.4
unnamed: LED39.2, LED40.4
unnamed: LED37.2, LED38.4
unnamed: LED34.2, LED35.4
unnamed: LED33.2, LED34.4
unnamed: LED29.2, LED30.4
unnamed: LED32.2, LED33.4
unnamed: LED31.2, LED32.4
unnamed: LED36.2, LED37.4
unnamed: LED40.2, LED41.4
unnamed: LED38.2, LED39.4
unnamed: LED35.2, LED36.4
unnamed: LED30.2, LED31.4
unnamed: LED50.2, LED51.4
unnamed: LED51.2, LED52.4
unnamed: LED52.2, LED53.4
unnamed: LED53.2, LED54.4
unnamed: LED48.2, LED49.4
unnamed: LED54.2, LED55.4
unnamed: LED55.2, LED56.4
unnamed: LED46.2, LED47.4
unnamed: LED43.2, LED44.4
unnamed: LED44.2, LED45.4
unnamed: LED45.2, LED46.4
unnamed: LED47.2, LED48.4
unnamed: LED49.2, LED50.4
unnamed: LED64.2, LED65.4
unnamed: LED65.2, LED66.4
unnamed: LED66.2, LED67.4
unnamed: LED67.2, LED68.4
unnamed: LED68.2, LED69.4
unnamed: LED69.2, LED70.4
unnamed: LED60.2, LED61.4
unnamed: LED58.2, LED59.4
unnamed: LED59.2, LED60.4
unnamed: LED61.2, LED62.4
unnamed: LED62.2, LED63.4
unnamed: LED63.2, LED64.4
unnamed: LED57.2, LED58.4
unnamed: LED78.2, LED79.4
unnamed: LED79.2, LED80.4
unnamed: LED80.2, LED81.4
unnamed: LED81.2, LED82.4
unnamed: LED83.2, LED84.4
unnamed: LED82.2, LED83.4
unnamed: LED74.2, LED75.4
unnamed: LED72.2, LED73.4
unnamed: LED73.2, LED74.4
unnamed: LED75.2, LED76.4
unnamed: LED76.2, LED77.4
unnamed: LED77.2, LED78.4
unnamed: LED71.2, LED72.4
unnamed: LED92.2, LED93.4
unnamed: LED93.2, LED94.4
unnamed: LED94.2, LED95.4
unnamed: LED95.2, LED96.4
unnamed: LED90.2, LED91.4
unnamed: LED96.2, LED97.4
unnamed: LED97.2, LED98.4
unnamed: LED88.2, LED89.4
unnamed: LED85.2, LED86.4
unnamed: LED86.2, LED87.4
unnamed: LED87.2, LED88.4
unnamed: LED89.2, LED90.4
unnamed: LED91.2, LED92.4
unnamed: LED106.2, LED107.4
unnamed: LED107.2, LED108.4
unnamed: LED108.2, LED109.4
unnamed: LED109.2, LED110.4
unnamed: LED104.2, LED105.4
unnamed: LED110.2, LED111.4
unnamed: LED111.2, LED112.4
unnamed: LED102.2, LED103.4
unnamed: LED99.2, LED100.4
unnamed: LED100.2, LED101.4
unnamed: LED101.2, LED102.4
unnamed: LED103.2, LED104.4
unnamed: LED105.2, LED106.4
unnamed: LED114.2, LED115.4
unnamed: LED120.2, LED121.4
unnamed: LED121.2, LED122.4
unnamed: LED122.2, LED123.4
unnamed: LED123.2, LED124.4
unnamed: LED118.2, LED119.4
unnamed: LED124.2, LED125.4
unnamed: LED125.2, LED126.4
unnamed: LED116.2, LED117.4
unnamed: LED113.2, LED114.4
unnamed: LED115.2, LED116.4
unnamed: LED117.2, LED118.4
unnamed: LED119.2, LED120.4
unnamed: LED134.2, LED135.4
unnamed: LED135.2, LED136.4
unnamed: LED136.2, LED137.4
unnamed: LED137.2, LED138.4
unnamed: LED138.2, LED139.4
unnamed: LED139.2, LED140.4
unnamed: LED130.2, LED131.4
unnamed: LED128.2, LED129.4
unnamed: LED129.2, LED130.4
unnamed: LED131.2, LED132.4
unnamed: LED132.2, LED133.4
unnamed: LED133.2, LED134.4
unnamed: LED127.2, LED128.4
unnamed: LED148.2, LED149.4
unnamed: LED149.2, LED150.4
unnamed: LED150.2, LED151.4
unnamed: LED151.2, LED152.4
unnamed: LED146.2, LED147.4
unnamed: LED152.2, LED153.4
unnamed: LED153.2, LED154.4
unnamed: LED144.2, LED145.4
unnamed: LED141.2, LED142.4
unnamed: LED142.2, LED143.4
unnamed: LED143.2, LED144.4
unnamed: LED145.2, LED146.4
unnamed: LED147.2, LED148.4
unnamed: LED162.2, LED163.4
unnamed: LED163.2, LED164.4
unnamed: LED164.2, LED165.4
unnamed: LED165.2, LED166.4
unnamed: LED166.2, LED167.4
unnamed: LED167.2, LED168.4
unnamed: LED158.2, LED159.4
unnamed: LED156.2, LED157.4
unnamed: LED157.2, LED158.4
unnamed: LED159.2, LED160.4
unnamed: LED160.2, LED161.4
unnamed: LED161.2, LED162.4
unnamed: LED155.2, LED156.4
unnamed: LED179.2, LED180.4
unnamed: LED174.2, LED175.4
unnamed: LED176.2, LED177.4
unnamed: LED177.2, LED178.4
unnamed: LED178.2, LED179.4
unnamed: LED180.2, LED181.4
unnamed: LED181.2, LED182.4
unnamed: LED169.2, LED170.4
unnamed: LED170.2, LED171.4
unnamed: LED171.2, LED172.4
unnamed: LED172.2, LED173.4
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

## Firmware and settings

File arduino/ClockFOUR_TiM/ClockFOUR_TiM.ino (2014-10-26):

#include <avr/pgmspace.h>
#include <Wire.h>      
#include <DS3231.h>

#include "bitmaps.h"

/************* Enable/disable debug mode *************/
#define DEBUG

#ifdef DEBUG
#define PRINT_DEBUG(x)		Serial.print(x)
#define PRINTLN_DEBUG(x)	Serial.println(x)
#else
#define PRINT_DEBUG(x)
#define PRINTLN_DEBUG(x)
#endif

/************* Pin settings *************/
#define MATRIX_PIN			5
#define BUTTON_L			6
#define BUTTON_R			A0
#define CAP_SENSE			A1
#define LDR_PIN				A7


/************* Some display settings *************/
#define MATRIX_WIDTH			16
#define MATRIX_HEIGHT			8
#define MIN_BRIGHTNESS			50
#define MAX_BRIGHTNESS			255

/************* Global time variablesrtc *************/
bool h12, PM;
DS3231 rtc;

/************* Types of button inputs *************/
typedef enum EventTypes {
	NO_EVENT = 0,
	BL_CLICK,        // Button left click
	BL_PRESS,        // Button left press
	BL_REPEAT,       // Button left repeat
	BR_CLICK,        // Button right click
	BR_PRESS,        // Button right press
	BR_REPEAT,       // Button right repeat
	EVENT_COUNT      // Number of event types in the queue
};

#define DEFAULT_REPEAT_DELAY		150      // number of milliseconds between each repeated button press (when held down)

/************* Colour modes *************/
typedef enum ColourModes {
	CM_ALL_WHITE = 0,
	CM_SOLID_COLOUR,
	CM_FADE,
	CM_RAINBOW,
	CM_PARTY,
	COLOUR_MODE_COUNT
};


/************* Display mode definitions *************/
typedef enum DisplayModeIdx {
	DISP_TIME = 0,
	DISP_SECONDS,
	DISP_TEMP,
	MODE_COUNT
};

uint8_t fade[MODE_COUNT] = {
	20,		// Time mode = fast fade
	40,		// Seconds mode = very fast fade
	0		// Temperature mode = no fade
};

typedef boolean (*DisplayModeFunc)(void);

DisplayModeFunc displayModes[MODE_COUNT] = {
	displayTime,
	displaySeconds,
	displayTemp
};


/************* Settings struct definition *************/
typedef union Settings {
	// WARNING: array has to be at least as large as the number of elements in the struct
	uint8_t array[9];
	struct {
		uint8_t useGPS;
		uint8_t useDegF;					// 0 if degrees C, 1 if degrees F
		uint8_t displayMode;				// Stores the display mode we are currently in
		uint8_t colourModes[MODE_COUNT];	// Each display mode has its own colour mode
		uint8_t colourVal[MODE_COUNT];		// Each display also has its own colour value
	};
};
extern Settings clockSettings;


/**** Main Code ****/

void setup() {
	// Start the serial port
	Serial.begin(9600);

	// Start one wire
	Wire.begin();

	// Initialise the board inputs and outputs
	pinMode(MATRIX_PIN, OUTPUT);   // declare the ledPin as an OUTPUT:
	pinMode(LDR_PIN, INPUT);       // declare the LDRPin as an INPUT:
	
	// Initialise the display
	disp_init();
	
	// Load the settings from the EEPROM
	loadSettings();
	
	// Initialise the buttons
	buttonsInit();

	// display a welcome message
	disp_setBrightness();
	disp_ScrollWords("Clock4", -40, 1);
		
	// enter self test mode if a button has been held down
	if (popEvent() != NO_EVENT) {
		self_test(); 
	}
}


void loop() {	
	// p_colourMode stores a pointer to the current colour mode
	uint8_t *p_colourMode = &clockSettings.colourModes[clockSettings.displayMode];
	uint8_t *p_colourValue = &clockSettings.colourVal[clockSettings.displayMode];
	
	buttonsTick();
	
	// Depending on the buttons pressed, take the necessary action
	switch(popEvent()) {
	case BL_CLICK:
		clockSettings.displayMode++;
		if(clockSettings.displayMode >= MODE_COUNT) {
			clockSettings.displayMode = 0;
		}
		
		clearBufferHistory();
		
		// Update p_colourMode to the new display mode
		p_colourMode = &clockSettings.colourModes[clockSettings.displayMode];
		p_colourValue = &clockSettings.colourVal[clockSettings.displayMode];
		
		PRINT_DEBUG("Switched to display mode: ");
		PRINTLN_DEBUG(clockSettings.displayMode);
		
		saveSettings();
		break;
		
	case BR_CLICK:
		// Perhaps enter colour settings mode?
		
		PRINT_DEBUG("Current colour mode: ");
		PRINTLN_DEBUG(*p_colourMode);

		(*p_colourMode)++;
		if(*p_colourMode >= COLOUR_MODE_COUNT) {
			*p_colourMode = 0;
		}
		
		PRINT_DEBUG("Switched to colour mode:");
		PRINTLN_DEBUG(*p_colourMode);
		
		saveSettings();
		break;
		
	case BR_PRESS:
		// Pick the colour
		*p_colourValue = colourConfig(*p_colourValue);
		*p_colourMode = CM_SOLID_COLOUR;
		clearBufferHistory();
		saveSettings();
		break;
		
	case BL_PRESS:
		// Configure the clock
		clockConfig();
		break;
		
	default:
		break;
	}
	
	// Set the display brightness from the LDR
	disp_setBrightness();

	// First clear all the LEDs, and then depending on the mode call its display function
	pixBuffer_clear();
	displayModes[clockSettings.displayMode]();
	
	// Figure out which colour mode we are using and then display the pixels
	disp_refresh(*p_colourMode, *p_colourValue, fade[clockSettings.displayMode]);
}


boolean displayTime() {
	// Sets and clears all pixels to show the current time in letters
	uint16_t totalMinutes = rtc.getHour(h12, PM) * 60 + rtc.getMinute();
	loadTime(totalMinutes);
}


boolean displaySeconds() {
	// Sets and clear all pixels to show the current seconds count
	pixBuffer_loadVal(rtc.getSecond(), 0);  // put a "2" in the last place to activate the minute slider
}


boolean displayTemp() {
	// Gets the temperature from the RTC and loads it into pixel buffer it in degrees C or F depending on settings
	float celsius = rtc.getTemperature();

	if (clockSettings.useDegF) {
		float fahrenheit = celsius * 9.0 / 5.0 + 32.0;
		pixBuffer_loadVal(fahrenheit, 1);
	} else {
		pixBuffer_loadVal(celsius, 1);
	}
}

uint8_t changeSetting(uint8_t origValue, uint8_t minimum, uint8_t maximum, uint16_t repeatDelay, void (*dispFunc)(uint8_t), uint16_t timeout = 0) {
	uint8_t value = origValue;
	long lastRepeat = millis();
	
	while(true) {
		buttonsTick();
		
		switch(popEvent()) {
			
		case BL_CLICK:
		case BL_PRESS:
			return value;
			
		case BR_CLICK:
		case BR_PRESS:
		case BR_REPEAT:
			if(millis() - lastRepeat < repeatDelay) {
				break;
			}
			
			lastRepeat = millis();
			
			value++;
			if(value > maximum) {
				value = minimum;
			}
			break;
			
		default:
			break;
		}
		
		if(timeout != 0 && lastRepeat + timeout < millis()) {
			return value;
		}
	
		dispFunc(value);
	}
	return value;
}


void colourWheelDisp(uint8_t colourMode) {
	// Configuration display function for the colour picker
	disp_refresh(CM_SOLID_COLOUR, colourMode, 0);
}


uint8_t colourConfig(uint8_t colourMode) {
	// Config function for the colour mode
	pixBuffer_clear();
	pixBuffer_loadBitmap(Circle_bw_bmp);
	
	return changeSetting(colourMode, 0, 255, 50, colourWheelDisp, 2000);
}


/************* Defines the different configuration modes *************/
typedef enum ConfigMode {
	GPS = 0,
	HOUR,
	MINUTE,
	TEMP_CF,
	LAST_MODE
};


// A bit of a hack - if we skip setting the time (because it is set through GPS)
// we jump to skip time. Not very elegant but will do for now
#define SKIP_TIME	MINUTE

void clockConfig() {
	
	uint8_t mode;

	// Don't give the GPS option if none is attached
	if(gpsPresent()) {
		mode = GPS;
	} else {
		mode = HOUR;
		clockSettings.useGPS = 0;
	}
	
	disp_showBWBitmap(Set_bw_bmp, 0x00FFFFFF, 0x00000000);
	waitDelayOrButton(1000);
	
	// Loop through all the configuration modes
	while(mode != LAST_MODE) {
		switch(mode) {
		case GPS:
			{
				disp_ScrollWords("GPS:", -15, 3);
				
				PRINTLN_DEBUG("Now entering GPS value");
				clockSettings.useGPS = changeSetting(clockSettings.useGPS, 0, 1, DEFAULT_REPEAT_DELAY, exampleDisplayFunction);
				if(clockSettings.useGPS) {
					mode = SKIP_TIME;
				}
			}
			break;
			
		case HOUR:
			{
				disp_showBWBitmap(Hour_bw_bmp, 0x00FFFFFF, 0x00000000);	// White on black
				waitDelayOrButton(2000);
				
				PRINTLN_DEBUG("Now entering hour value");
				rtc.setHour(changeSetting(rtc.getHour(h12, PM), 0, 23, DEFAULT_REPEAT_DELAY, disp_displayVal));
			}
			break;
			
		case MINUTE:
			{
				disp_showBWBitmap(Min_bw_bmp, 0x00FFFFFF, 0x00000000);	// White on black
				waitDelayOrButton(2000);
				
				PRINTLN_DEBUG("Now entering minute value");
				rtc.setMinute(changeSetting(rtc.getMinute(), 0, 59, DEFAULT_REPEAT_DELAY, disp_displayVal));
				
				// Set seconds to 0 for a clean start to the minute
				rtc.setSecond(0);
			}
			break;
			
		case TEMP_CF:
			{
				disp_showBWBitmap(Temp_bw_bmp, 0x00FFFFFF, 0x00000000);	// White on black
				waitDelayOrButton(2000);

				PRINTLN_DEBUG("Now entering whether temp should be represented in C (0) or F (1)");
				clockSettings.useDegF = changeSetting(clockSettings.useDegF, 0, 1, DEFAULT_REPEAT_DELAY, disp_TempCF);
			}
			break;
			
		default:
			break;
		}
		
		// Select the next config mode
		mode++;
	}
	
	saveSettings();
	PRINTLN_DEBUG("Exiting configuration mode");
}


// Creates a delay loop that exits when either the time given
// has passed, or one of the buttons has been pressed
uint8_t waitDelayOrButton(uint16_t delayTime) {
	unsigned long stopTime = millis() + delayTime;
	uint8_t retVal = NO_EVENT;
	
	while(millis() < stopTime) {
		buttonsTick();
		retVal = popEvent();
		if(retVal == BL_CLICK || retVal == BR_CLICK) {
			// A click event has happened, quit the loop early
			break;
		}
	}
	
	return retVal;
}


void exampleDisplayFunction(uint8_t value) {
	PRINTLN_DEBUG(value);
}

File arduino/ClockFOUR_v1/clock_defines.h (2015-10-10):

/*
*  ClockFOUR settings and typedef file
*
*
*  Author: Josef Schneider
*  Licence: http://creativecommons.org/licenses/by/3.0/
*
*  Description:
*    This file contains all the non-configurable settings for the clock.
*  The different types used throughout the project are also defined here.
*
*/

#ifndef CLOCK_DEFINES_H_
#define CLOCK_DEFINES_H_

/************* Enable/disable debug mode *************/
//#define DEBUG

#ifdef DEBUG
#define PRINT_DEBUG(x)			Serial.print(x)
#define PRINTLN_DEBUG(x)		Serial.println(x)
#else
#define PRINT_DEBUG(x)
#define PRINTLN_DEBUG(x)
#endif

/************* Pin settings *************/
#define MATRIX_PIN			2
#define BUTTON_L			3
#define BUTTON_R			4
#define	LOGO_PIN			5
#define	LOGO_SENSE			6

#define LDR_PIN1			A1
#define LDR_PIN2			A0
#define LDR_PIN3			A2

/************* Some display settings *************/
#define MATRIX_WIDTH			14
#define MATRIX_HEIGHT			13

/************* Company logo settings *************/
#define ENABLE_COMPANY_LOGO		false
#define LOGO_LED_COUNT			20

/************* Timing related settings *************/
#define DEFAULT_REPEAT_DELAY	150     // number of milliseconds between each repeated button press (when held down)
#define TIME_MODE_FADE_SPEED	20		// Time mode = fast fade
#define SEC_MODE_FADE_SPEED		40		// Seconds mode = very fast fade
#define REFRESH_PERIOD			20		// Determines the refresh period of the displays, in this case 20ms
// WARNING! The fade speeds depend on this frequency. Increasing this
// number will slow down fade speeds.

/************* Brightness related settings *************/
#define MIN_BRIGHTNESS			60		// Minimum brightness
#define MAX_BRIGHTNESS			255		// Maximum brightness we want to subject the user to
#define BRIGHTNESS_LEVELS		5		// Number of static brightness levels the user can configure
#define BRIGHTNESS_REFRESH		25		// Refresh rate of the brightness changes, in ms
#define BRIGHTNESS_INCR			1		// Rate at which the brightness levels changes. 1 = 1 increment per refresh cycle

// Hysteresis is used in the brightness logic to stabilise the
// brightness value. Larger width values should be used for 
// less stable sensors with the disadvantage that brightness
// changes will be more noticable/step-like.
#define BRIGHTNESS_HYSTERESIS_WIDTH		5

// The LDR min and max values represent the min and max 10-bit values
// that represent the voltage range of the sensor used.
#define LDR_MIN_BRIGHTNESS		60
#define LDR_MAX_BRIGHTNESS		800

/************* Types of button inputs *************/
typedef enum EventTypes {
	NO_EVENT = 0,
	BL_CLICK,        // Button left click
	BL_PRESS,        // Button left press
	BL_REPEAT,       // Button left repeat
	BR_CLICK,        // Button right click
	BR_PRESS,        // Button right press
	BR_REPEAT,       // Button right repeat
	EVENT_COUNT      // Number of event types in the queue
};

/************* Colour modes *************/
typedef enum ColourModes {
	CM_ALL_WHITE = 0,
	CM_SOLID_COLOUR,
	CM_FADE,
	CM_RAINBOW,
	CM_PARTY,
	COLOUR_MODE_COUNT
};


/************* Display mode definitions *************/
typedef enum DisplayModeIdx {
	DISP_TIME = 0,
	DISP_SECONDS,
	MODE_COUNT
};

typedef boolean(*DisplayModeFunc)(void);

/************* Settings struct definition *************/
typedef struct Settings {
	uint8_t useDegF;					// 0 if degrees C, 1 if degrees F
	uint8_t displayMode;				// Stores the display mode we are currently in
	uint8_t colourModes[MODE_COUNT];	// Each display mode has its own colour mode
	uint8_t colourVal[MODE_COUNT];		// Each display also has its own colour value
	uint8_t logoColourMode;
	uint8_t logoColourVal;
	uint8_t brightnessMode;				// 0 = Auto, 1 - 5 = static brightness levels
};

#endif // CLOCK_DEFINES_H_

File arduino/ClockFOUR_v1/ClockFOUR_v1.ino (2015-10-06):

/*
 *  ClockFOUR_v1 main file
 * 
 * 
 *  Author: Josef Schneider
 *  Licence: http://creativecommons.org/licenses/by/3.0/
 *
 *  Description:
 *    This file contains the application entry points, and also the code dealing with 
 *  the user interface.
 *
 *  To allow entry-level developers to make changes without having to tackle cpp libraries,
 *  most of the code is located in .ino files.
 *
 */

#include <Wire.h>
#include <DS3231.h>

#include "clock_defines.h"	// <- Any setting changes need to be made here
#include "bitmaps.h"

/************* Global variables *************/
bool h12, PM;
DS3231 rtc;

// fade defines how quickly letters fade depending
// on the display mode
const uint8_t fade[MODE_COUNT] = {
	TIME_MODE_FADE_SPEED,
	SEC_MODE_FADE_SPEED
};

// Display function pointers for the different display modes. This approach
// is not the safest but makes adding new display modes extremely easy.
const DisplayModeFunc displayModes[MODE_COUNT] = {
	displayTime,
	displaySeconds,
};

bool companyLogoEnabled = false;

/******* Externs ********/
// clockSettings is defined in settings.ino
extern Settings clockSettings;

/**** Main Code ****/

void setup() {
	// Start the serial port
	Serial.begin(9600);

	// Start one wire
	Wire.begin();
	
	pinMode(LDR_PIN1, INPUT);       // declare the LDRPin as an INPUT:
	pinMode(LDR_PIN2, INPUT);
	pinMode(LDR_PIN3, INPUT);

	brightness_init(LDR_PIN1);		// , LDR_PIN2, LDR_PIN3);

	pinMode(LOGO_SENSE, INPUT);
	companyLogoEnabled = (digitalRead(LOGO_SENSE) == LOW) && ENABLE_COMPANY_LOGO;

	// Initialise the board inputs and outputs
	pinMode(MATRIX_PIN, OUTPUT);	// declare the ledPin as an OUTPUT:
	pinMode(LOGO_PIN, OUTPUT);

	// Load the settings from the EEPROM
	loadSettings();
	
	// Initialise the display
	disp_init(clockSettings.brightnessMode);
	
	// Initialise the buttons
	buttonsInit();
        
	// display a welcome message
#ifndef DEBUG
	disp_ScrollWords("Chronogram", -55, 1);
#endif
		
	// enter self test mode if a button has been held down
	if (popEvent() != NO_EVENT) {
		clearQueue();
		self_test(); 
	}
}


void loop() {	
	// p_colourMode and p_colourValue are pointers to the current colour mode and value
	uint8_t *p_colourMode = &clockSettings.colourModes[clockSettings.displayMode];
	uint8_t *p_colourValue = &clockSettings.colourVal[clockSettings.displayMode];
	
	buttonsTick();
	
	// Depending on the latest even (e.g., button press), take the necessary action
	switch(popEvent()) {
	case BL_CLICK:
		clockSettings.displayMode++;
		if(clockSettings.displayMode >= MODE_COUNT) {
			clockSettings.displayMode = 0;
		}
		
		pixBuffer_clearHistory();
		
		// Update p_colourMode to the new display mode
		p_colourMode = &clockSettings.colourModes[clockSettings.displayMode];
		p_colourValue = &clockSettings.colourVal[clockSettings.displayMode];
		
		PRINT_DEBUG("Switched to display mode: ");
		PRINTLN_DEBUG(clockSettings.displayMode);
		
		saveSettings();
		break;
		
	case BR_CLICK:
		// A right button click has been detected
		PRINT_DEBUG("Current colour mode: ");
		PRINTLN_DEBUG(*p_colourMode);

		(*p_colourMode)++;
		if(*p_colourMode >= COLOUR_MODE_COUNT) {
			*p_colourMode = 0;
		}
		
		PRINT_DEBUG("Switched to colour mode:");
		PRINTLN_DEBUG(*p_colourMode);
		
		saveSettings();
		break;
		
	case BR_PRESS:
		// Pick the colour
		*p_colourValue = colourConfig(*p_colourValue);
		*p_colourMode = CM_SOLID_COLOUR;
		pixBuffer_clearHistory();
		saveSettings();
		break;
		
	case BL_PRESS:
		// Configure the clock
		clockConfig();
		break;
		
	default:
		break;
	}
	
	// Set the display brightness from the LDR
	disp_setBrightness(clockSettings.brightnessMode);

	// First clear all the LEDs, and then depending on the mode call its display function
	pixBuffer_clear();
	displayModes[clockSettings.displayMode]();
	
	// Figure out which colour mode we are using and then display the pixels
	disp_refresh(*p_colourMode, *p_colourValue, fade[clockSettings.displayMode]);
	
	if(companyLogoEnabled) {
		updateLogoColour(clockSettings.logoColourMode, clockSettings.logoColourVal);
	}
    PRINTLN_DEBUG();
}


boolean displayTime() {
	// Sets and clears all pixels to show the current time in letters
	uint16_t totalMinutes = rtc.getHour(h12, PM) * 60 + rtc.getMinute();
	loadTime(totalMinutes);
}


boolean displaySeconds() {
	// Sets and clears all pixels to show the current seconds count
	pixBuffer_loadVal(rtc.getSecond());
}


// Generic value input function with configurable display function
uint8_t changeSetting(
		const uint8_t origValue,		// Starting value
		const uint8_t minimum,			// Minimum possible value
		const uint8_t maximum,			// Maximum possible value
		const uint16_t repeatDelay,		// Delay between repeat presses if button is held down in ms
		void(*dispFunc)(uint8_t),		// Pointer to the function to be used to display the value
		const uint16_t timeout = 0) {	// Amount of time after which this function exists if no input

	uint8_t value = origValue;
	long lastRepeat = millis();
	
	while(true) {
		buttonsTick();
		
		switch(popEvent()) {
			
		case BL_CLICK:
		case BL_PRESS:
			return value;
			
		case BR_CLICK:
		case BR_PRESS:
		case BR_REPEAT:
			if(millis() - lastRepeat < repeatDelay) {
				break;
			}
			
			lastRepeat = millis();
			
			value++;
			if(value > maximum) {
				value = minimum;
			}
			break;
			
		default:
			break;
		}
		
		if(timeout != 0 && lastRepeat + timeout < millis()) {
			return value;
		}
	
		dispFunc(value);
	}
	return value;
}


// Special colour picker to set the colour mode and value for the company logo
void colourPickerChangeSetting() {
	long lastRepeat = millis();
	
	while(true) {
		buttonsTick();
		
		switch(popEvent()) {
			
		case BL_CLICK:
		case BL_PRESS:
			return;
		
		case BR_CLICK:
			clockSettings.logoColourMode++;
			if(clockSettings.logoColourMode >= CM_PARTY) {
				clockSettings.logoColourMode = 0;
			}
		
			PRINT_DEBUG("Switched to logo colour mode:");
			PRINTLN_DEBUG(clockSettings.logoColourMode);
			break;
			
		case BR_PRESS:
		case BR_REPEAT:
			if(millis() - lastRepeat < 50) {
				break;
			}
		
			PRINT_DEBUG("Switched to logo colour value:");
			PRINTLN_DEBUG(clockSettings.logoColourVal);
		
			lastRepeat = millis();
			
			clockSettings.logoColourVal++;
			clockSettings.logoColourMode = CM_SOLID_COLOUR;
			break;
		
		default:
			break;
		}
				
		disp_refresh(clockSettings.logoColourMode, clockSettings.logoColourVal, 0);
	}
}


void colourWheelDisp(const uint8_t colourMode) {
	// Configuration display function for the colour picker
	disp_refresh(CM_SOLID_COLOUR, colourMode, 0);
}


uint8_t colourConfig(const uint8_t colourMode) {
	// Config function for the colour mode
	pixBuffer_clear();
	pixBuffer_loadBitmap(Circle_bw_bmp, 0, 0);
	
	return changeSetting(colourMode, 0, 255, 50, colourWheelDisp, 2000);
}


/************* Defines the different configuration modes *************/
typedef enum ConfigMode {
	HOUR,
	MINUTE,
	BRIGHTNESS,
	LOGO_COLOUR,
	LAST_MODE
};
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

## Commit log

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2014-08-20 Created faceplate and baffles for 30x30 clock
    [charlie tag.dxf, english_TiM_UPPER Helvetica_TiM_1.0.dxf]
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2014-08-22 Created language files for Clock_TiM and Clock_30
    [English_TiM layout helper.xlsx]
2014-08-22 Directory cleanup
    [LANGUAGE layout helper.xlsx]
2014-08-22 Seconds displayed + updates to library
    NeoMatrix + NeoPixel instances running at the same time
    [LANGUAGE layout helper.xlsx]
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2014-08-25 Added Cap sense switches
    Replaced buttons with touch sensors
    [Various layouts.xlsx, baffles_jr_30_1.0.dxf]
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2014-08-30 Wrote ButtonTest program to test input keys
    Input is not working as expected.
    [ButtonTest.ino, getCapButtons.ino]
2014-09-04 RTC?
    Poor attempt to add RTC code. Not working.
    [ClockFOUR_TiM.ino, LED_Display.ino]
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2014-09-12 ClockFOUR_30 is alive!
    [backplate guide.dxf, baffles_jr_30_1.0.dxf]
2014-09-15 Clock_30 updates
    [baffles_jr_30_1.0.dxf]
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2014-10-01 Schematic updated, board started
    [ClockFOUR.kicad_pcb, ClockFOUR.sch, Row_A.sch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]
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2014-10-03 Board layout updated
    Matrix placed and wired. Added RTC.
    [ClockFOUR.kicad_pcb, ClockFOUR.sch, Row_A.sch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]
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2014-10-06 Layout updated
    added 4x caps on power input. Replace with single larger cap??
    [ClockFOUR.kicad_pcb, ClockFOUR.sch]
2014-10-06 Completed Layout for review
    Version alpha 0.1
    [ClockFOUR.kicad_pcb, ClockFOUR.sch, Row_A.sch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]
2014-10-07 Layout changes
    + increased size of 5V traces
    + board notch around RTC battery
    + added breakout pins
    [ClockFOUR.kicad_pcb, ClockFOUR.sch, Row_A.sch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]
2014-10-08 Layout updated
    Fixed thin trace clearance error on ucontroller.
    [ClockFOUR.kicad_pcb]
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2014-10-08 Anool's version of pcb saved as ClockFOUR_anool.kicad_pcb
    [ClockFOUR.kicad_pcb, ClockFOUR.sch, ClockFOUR_anool.kicad_pcb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]
2014-10-09 Connector nudged, sent to Seed for quotation
    [ClockFOUR-B_Cu.gbl, ClockFOUR-B_Paste.gbp, ClockFOUR-B_SilkS.gbo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]
2014-10-09 New power jack added
    [ClockFOUR.kicad_pcb]
2014-10-09 PCB layout, work in progress
    [ClockFOUR.kicad_pcb, ClockFOUR.sch, Row_A.sch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]
2014-10-10 C4 PCB layout complete. Added Gerbers
    [ClockFOUR-B_Cu.gbl, ClockFOUR-B_Mask.gbs, ClockFOUR-B_Paste.gbp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]
2014-10-10 C4 PCB layout complete. BoM in progress
    [ClockFOUR-B_Cu.gbl, ClockFOUR-B_Mask.gbs, ClockFOUR-B_Paste.gbp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]
2014-10-10 C4 board layout complete. Gerbers and BoM ready
    [ClockFOUR-B_Cu.gbl, ClockFOUR-B_Mask.gbs, ClockFOUR-B_Paste.gbp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]
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2014-10-11 C4 added spare buttons, SMD push buttons, I2C address ports etc
    [ClockFOUR.sch, ClockFOUR_BoM_pcb.csv, ClockFOUR_BoM_sch.csv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]
2014-10-13 C4 added NiL header
    [ClockFOUR-B_Cu.gbr, ClockFOUR-B_Mask.gbr, ClockFOUR-B_Paste.gbr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]
2014-10-14 C4 some minor mods to PCB layout
    [ClockFOUR-B_Cu.gbr, ClockFOUR-B_Mask.gbr, ClockFOUR-B_Paste.gbr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]
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2014-10-16 Nil header, added SMD switches, BoM modified
    [ClockFOUR-B_Cu.gbl, ClockFOUR-B_Cu.gbr, ClockFOUR-B_Mask.gbr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]
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2014-10-20 C4 final prototype Gerbers ready
    [ClockFOUR-B_Cu.gbl, ClockFOUR-B_Cu.gbr, ClockFOUR-B_Mask.gbr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]
2014-10-26 Clock_30: centred letters, fixed text wrap
    [ClockFOUR_30.ino, LED_Display.ino]
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2014-12-12 Removed cap sense, added button code
    Works with buttons on the back of the clock
    [1.2mm baffles.dxf, 1.4cm baffles.dxf, C4 sides 26mm.dxf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]
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2015-01-09 working on rev 2 of ClockFOUR
    [Barrel_Socket_STL_PJ-047A.stl, Barrel_Socket_STL_PJ-047B.stl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]
2015-01-21 Schematic Changes
    1. Touch circuitry removed. Pins changed to breakout pins.
    2. "Name in Lights" and NiL changed to "Marquee"
    3. P10 connector - added 4th pin
    1. MARQUEE_DATA (through a 470R resistor)
    2. MARQUEE_SENSE pin pulled high via 10k resistor. When this pin is
    grounded clock knows Marquee is connected
    3. GND
    4. 5V
    4. Added internal surface mount LDR next to an existing LED - would like
    to test this on next prototype so we don't need to externally mount the
    LDR.
    5. Remove power connector, move to soldered wires to panel mount socket
    (per your suggestion)
    6. FYI - the name for the clock will likely change shortly. The "C4"
    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
    [ClockFOUR.sch, Row_A.sch, Row_B.sch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]
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2015-01-23 Schematic changes - 3x LDR
    3x LDR's to be placed below LED1, LED14 and LED121.
    Removed external LDR header.
    [ClockFOUR.sch, Row_A.sch, Row_B.sch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]
2015-01-26 Updated mechanical design
    Faceplate and baffle generation script updates
    Assembly mock-up drawing updated
    [1.4cm baffles.dxf, 1.4cm baffles_v2.dxf, 1.4cm baffles_v3.dxf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]
2015-01-26 C4 rev2 aka Chronogram, Sch and PCB mods, revised BoM
    [ClockFOUR-B_Cu.gbl, ClockFOUR-B_Mask.gbs, ClockFOUR-B_Paste.gbp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]
2015-01-27 Added Fuse/Zener protection, silk legend mods
    [ClockFOUR-B_Cu.gbl, ClockFOUR-B_Mask.gbs, ClockFOUR-B_Paste.gbp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]
2015-01-27 Minor board tweaks
    Trying to add a logo to the back of the board
    [ClockFOUR.sch, Row_A.sch, Row_B.sch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]
2015-01-28 Assembly C4_v2 folder created
    Assembly BOM updated
    created folder to send Seeed for latest prototype
    [c3jr_v2_BoM_seeed_RetailClock.xls]
2015-01-29 Headers moved, Silk Legend update, BoM update, Gerber generated
    [ClockFOUR-B_Cu.gbl, ClockFOUR-B_Mask.gbs, ClockFOUR-B_Paste.gbp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]
2015-01-29 Revised backplate
    Added backplate cut out holes and etching
    [backplate guide.dxf, baffles_jr_30_1.0.dxf, c3jr_v2_BoM_seeed_RetailClock.xls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]
2015-01-29 Revised clock sides, added test plan and instructions
    [c3jr_v2_BoM_seeed_RetailClock.xls]
2015-01-30 V2 Files sent to Seeed
    [c4_v2_BoM_seeed.xlsx]
2015-01-30 Version 2.1 - sent to Seeed
    Adjusted FTDI cutout hole down 4mm
    [c3jr_v2_BoM_seeed_RetailClock.xls, c4_v2_BoM_seeed.xlsx]
2015-01-31 Brightness no longer changes in a linear manner
    [LED_Display.ino]
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2015-10-06 Kicad mods done. Gerbers, PDF ready
    [Barrel_Socket_STL_PJ-047A.stl, Barrel_Socket_STL_PJ-047B.stl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]
2015-10-07 ver 3.0 BoM finalized
    [ClockFOUR_BoM_pcb.csv, ClockFOUR_BoM_sch.csv, c4_v2_BoM_seeed.ods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]
2015-10-10 Preparing for final design changes
    Moving files to their new location, minor changes to baffles.
    [ClockFOUR-B_Cu.gbl, ClockFOUR-B_Mask.gbs, ClockFOUR-B_Paste.gbp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]
2015-10-12 ClockFOUR ver 3.0 final schematic, layout, gerber plots and BoM for production
    [ClockFOUR-B_Cu.gbl, ClockFOUR-B_Mask.gbs, ClockFOUR-B_Paste.gbp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]
2015-10-12 added 3D printable bracket for power socket wall mounting option
    [C4_bracket.fcstd, C4_bracket.stl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]
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
